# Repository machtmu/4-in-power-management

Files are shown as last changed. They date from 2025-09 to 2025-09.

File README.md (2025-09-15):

# 4 Inch Power Management Subsystem
I'm not gonna lie, this was a beast  

As part of the SPRINT ecosystem with MACH, this board was deisgned in the span of 5 days (From architecture to schematic to layout to production). These were not a good 5 days   

## Functionality
4 Cell BMS with high side protection FETs, integrated NVDC charging for up to 5A @ battery voltage, 3 power rails, 5V, 3.3V @ ~3A, 24V @1.8A (Shoutout Tristan)   
BMS supports up to ~5.7A due to the FET's, but if re speced, could probably go higher   
XT30's as output for 24V, input for charger and input for battery   
JST XH as input for cell balacing   
 Low side current sensing for OCP detection (or wtv else you need current for)  
 ## TODO:  
 I should change that load resistor but lowkey too tired rn :wilted_rose:   
 Order it lmao  
# Authors:  
 Architecture: javezki  
 BMS, 5V 3.3V: javezki  
 Charger, 24V Boost: kayessi 
 Layout: javezki
---

<div align="center">
  <div>
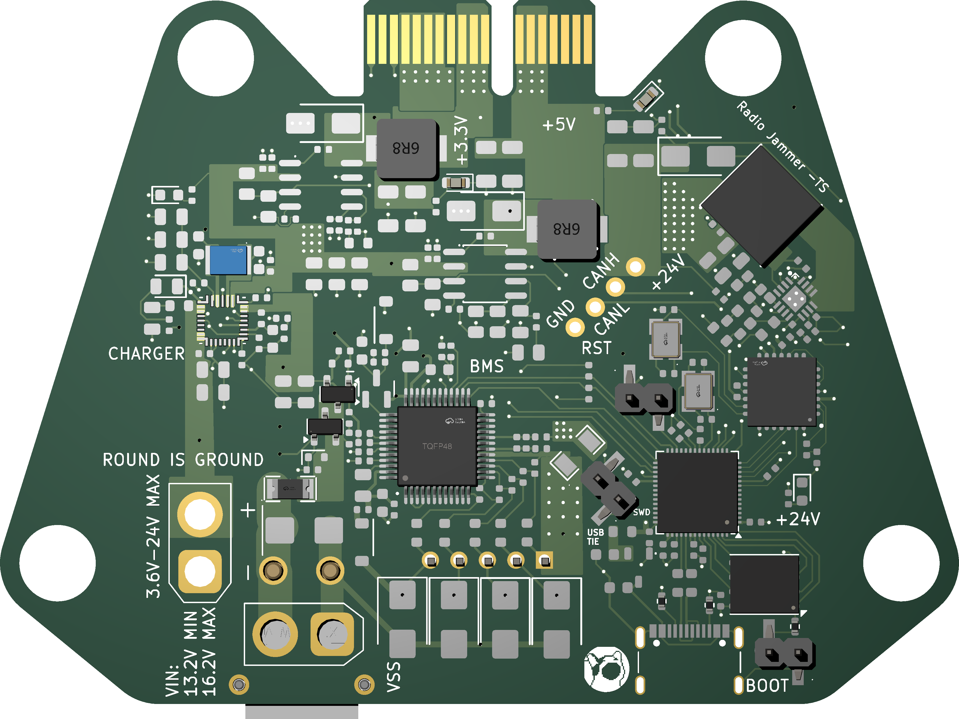
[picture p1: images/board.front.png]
    
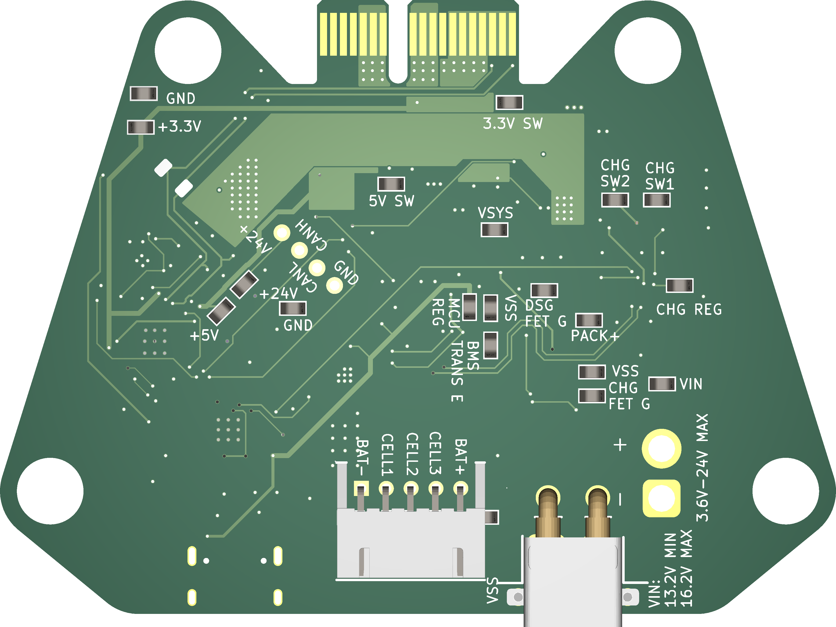
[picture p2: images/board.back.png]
    
    <p><em>3D Render</em></p>
  </div>
  <br>

  <div>
    Schematic<br>
    <p><em>Schematic</em></p>
  </div>
  <br>
  
  <div>
    Front
    Back<br>
    <em>Footprint</em>
  </div>
</div>

Use Export KiCad Images Workflow

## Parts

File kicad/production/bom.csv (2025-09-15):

Designator | Footprint | Quantity | Value | LCSC Part #
C1, C2, C33, C34, C36, C75 | C_0603 | 6 | 1uF | C15849
C10, C17 | C_0402 | 2 | 1uF | C52923
C11, C12, C23, C24, C25, C26, C78 | C_0402 | 7 | 220nF | C16772
C13, C14, C15, C16, C18, C29, C37, C38, C46, C47, C5, C51, C6, C61, C67, C7, C74, C76, C77, C8, C81, C9 | C_0402 | 22 | 100nF | C307331
C19 | C_0402 | 1 | 4.7nF | C1538
C20 | C_0805 | 1 | 33pF | C107115
C21, C41 | C_0402 | 2 | 1nF | C1523
C22 | C_0402 | 1 | 47pF | C1567
C27, C70 | C_0805 | 2 | 1uF | C28323
C28, C32 | C_0402 | 2 | 100pF | C1546
C3, C4 | C_0402 | 2 | 15pF | C1548
C30 | C_0402 | 1 | 2.2uF | C12530
C31 | C_0805 | 1 | 470nF | C13967
C35 | C_0805 | 1 | 22uF | C45783
C39, C43, C44 | C_0603 | 3 | 47nF | C1622
C40, C42, C49, C50, C52, C53, C54, C55, C56, C57 | C_0805 | 10 | 10uF | C440198
C45, C58, C59, C64, C65 | C_0402 | 5 | 4.7uF | C23733
C48 | C_0805 | 1 | 2.2uF | C377773
C60, C66, C73 | C_0402 | 3 | 10nF | C15195
C62, C63, C68, C69 | C_1206 | 4 | 47uF | C96123
C71 | C_0603 | 1 | 330pF | C1664
C72 | C_0603 | 1 | 8.2nF | C1322360
C79, C80 | C_1206 | 2 | 4.7uF | C29823
D1, D2 | 0603 | 2 | LED | C2286
D10, D11 | D_SOD-123 | 2 | BAT46W | C7420332
D12, D9 | D_SOD-523 | 2 | BZX584C12 | C22395579
D13 | D_0805 | 1 | Green | C2297
D14, D15 | D_SMA | 2 | SSL54 | C41410770
D16 | D_SMA | 1 | SS54 | C22452
D17, D3 | D_0603 | 2 | Yellow | C89811
D4, D5, D6, D7, D8 | D_SMB | 5 | SMBJ18A | C19077573
F1 | F1206 | 1 | 0501015_WR | C126815
J1 | USB_C_Receptacle_Palconn_UTC16-G | 1 | USB_C_Receptacle_USB2.0_16P | C2765186
L1 | IND-SMD_L3.2-W2.5-1 | 1 | 1uH | C5159968
L2 | IND-SMD_L7.5-W7.5_XAL7030 | 1 | 2.7uH | C5366402
Q1 | Q_SOT-23 | 1 | FMMT493 | C28646275
Q2, Q3 | SOT-23 | 2 | AO3400A
R1, R12, R13, R2 | 0402 | 4 | 5.1k | C25905
R10, R9 | 0402 | 2 | 27 | C25100
R11, R28, R29, R30, R31, R34, R37, R40, R42, R5, R56, R57 | R_0402 | 12 | 10kΩ | C25744
R14 | R_0805 | 1 | 6.2kΩ | C17767
R15 | R_0805 | 1 | 1.2kΩ | C17379
R16 | R_0805 | 1 | 51kΩ | C17737
R17, R41 | R_0402 | 2 | 7.5kΩ | C25918
R18 | R_0402 | 1 | 2.4kΩ | C25882
R19 | R_0603 | 1 | 30kΩ | C22984
R20, R21, R22, R23, R24 | R_0603 | 5 | 20Ω | C22950
R25, R27, R32, R35, R36, R39 | R_0402 | 6 | 100Ω | C25076
R26 | R0805 | 1 | 5mΩ | C92742
R3, R4, R7 | 0402 | 3 | 1k | C11702
R33, R38 | R_0402 | 2 | 10MΩ | C26082
R43 | R_0402 | 1 | 2.2kΩ | C25879
R44 | R_0603 | 1 | 2Ω | C22977
R45, R47 | R_0805 | 2 | 330kΩ | C17629
R46, R48 | R_0805 | 2 | 100kΩ | C149504
R49, R50 | R_0603 | 2 | 470Ω | C23179
R51 | R_0603 | 1 | 9.1kΩ | C23260
R52 | R_0603 | 1 | 5.1Ω | C25197
R53 | R_0402 | 1 | 47kΩ | C25792
R54 | R_0402 | 1 | 2kΩ | C4109
R55 | R_0402 | 1 | 47Ω | C25118
R6 | R_0603 | 1 | 0Ω | C21189
R8 | R_0402 | 1 | 1kΩ | C11702
TP1, TP10, TP11, TP12, TP13, TP14, TP15, TP16, TP17, TP18, TP19, TP2, TP20, TP21, TP22, TP23, TP24, TP3, TP4, TP5, TP6, TP7, TP8, TP9 | SMD_RH-5015 | 24 | RH-5015 | C5199798
U1 | SOT-23-3_L2.9-W1.6-P1.90-LS2.8-BR | 1 | XC6206P332MR | C5446
U10 | IC_BQ25672RQMR | 1 | BQ25672RQMR | C3682029
U11, U13 | SOIC-8_L5.0-W4.0-P1.27-LS6.0-BL | 2 | TPS54331DR | C9865
U12, U14 | IND-SMD_L5.4-W5.2_SLO0530H6R8MTT | 2 | 6.8uH | C325965
U15 | WQFN-16_L3.0-W3.0-P0.50-TL-EP1.7 | 1 | LM5157RTER | C5219222
U17, U2, U4 | HDR-SMD_2P-P2.54-V-M-S4.8_DZ254S-11-02-50 | 3 | 2P SMD 2.54P Jumper | C17702633
U3 | WSON-8-1EP_6x5mm_P1.27mm_EP3.4x4.3mm | 1 | W25Q128JVP | C190862
U5 | QFN-28_L6.0-W6.0-P0.65-BL-EP3.7 | 1 | MCP25625T-E/ML | C191253
U6 | QFN-56-1EP_7x7mm_P0.4mm_EP3.2x3.2mm | 1 | RP2040 | C2040
U7 | CONN-TH_5P-P2.50_S5B-XH-A-LF-SN | 1 | S5B-XH-A(LF)(SN) | C263757
U8 | CONN-TH_XT30PW-M | 1 | XT30PW-M | C431092
U9 | TQFP-48_L7.0-W7.0-P0.50-LS9.0-TL | 1 | BQ7694202PFBR | C3682863
X1 | CRYSTAL-SMD_4P-L3.2-W2.5-BL | 1 | ABM8-272-T3 | C20625731
Y1 | CRYSTAL-SMD_4P-L3.2-W2.5-BL | 1 | X322516MLB4SI | C12668

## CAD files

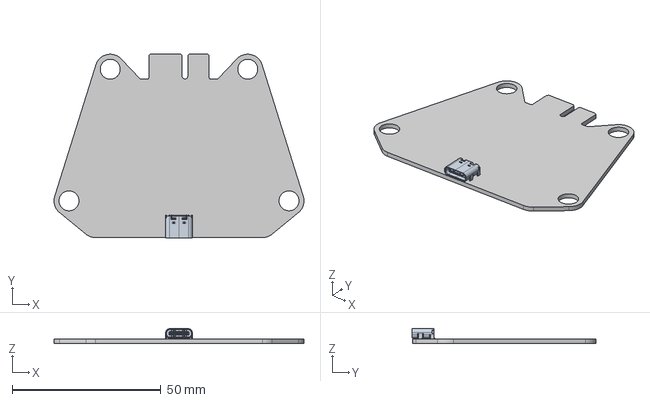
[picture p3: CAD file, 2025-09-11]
images/board.step
84.1 x 61.9 x 4.91 mm
USB_C_Receptacle_GCT_USB4105-xx-A_16P_TopMnt_Horizontal
template_PCB

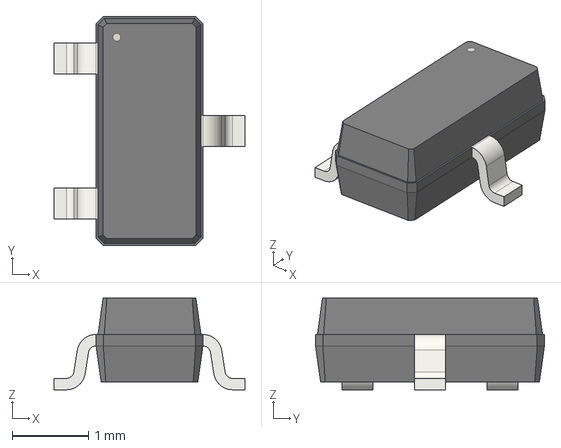
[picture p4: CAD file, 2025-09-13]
kicad/models/SOT-23.step
2.50 x 3.00 x 1.20 mm

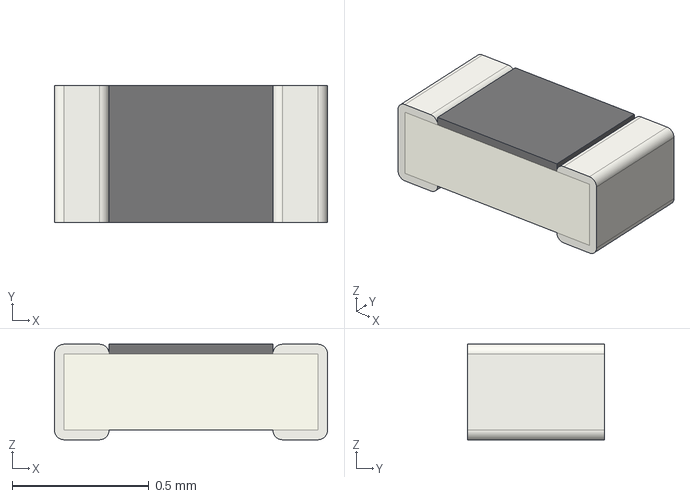
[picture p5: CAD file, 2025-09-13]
kicad/models/R_0402_1005Metric.step
1.00 x 0.5 x 0.35 mm

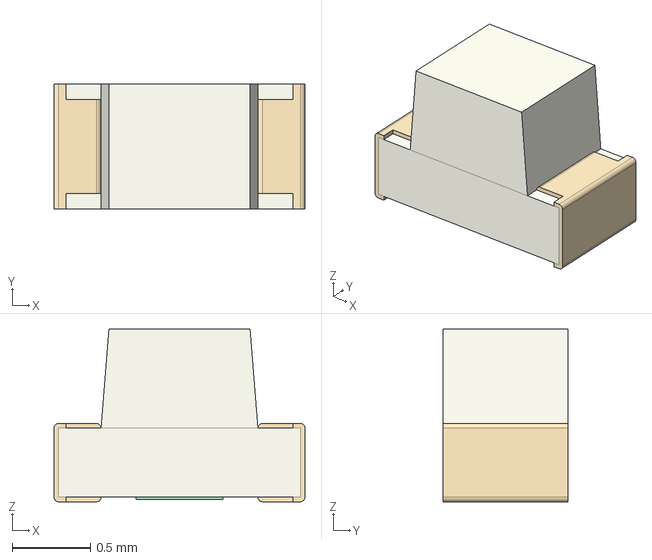
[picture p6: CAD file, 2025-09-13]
kicad/models/LED_0603_1608Metric.step
1.60 x 0.8 x 1.10 mm

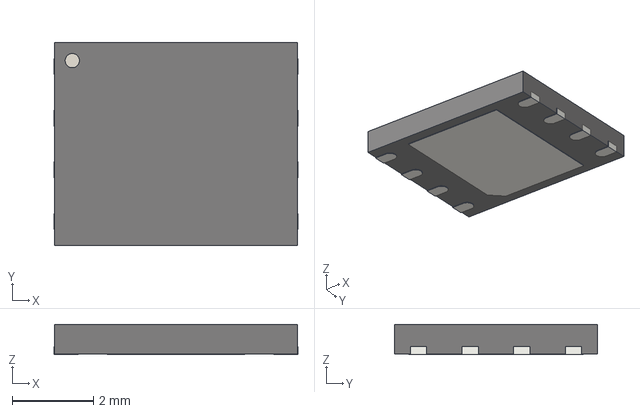
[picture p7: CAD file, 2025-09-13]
kicad/models/WSON-8-1EP_6x5mm_P1.27mm_EP3.4x4.3mm.step
6.00 x 4.98 x 0.75 mm

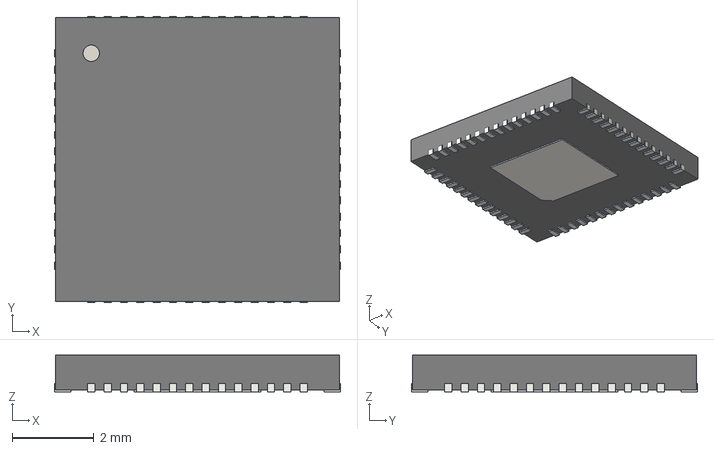
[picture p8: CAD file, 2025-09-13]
kicad/models/QFN-56-1EP_7x7mm_P0.4mm_EP3.2x3.2mm.step
7.00 x 7.00 x 0.9 mm

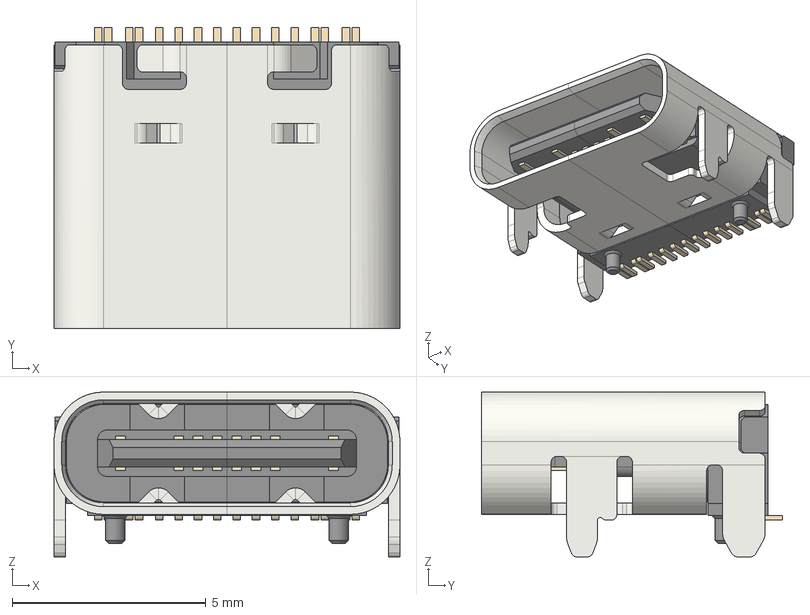
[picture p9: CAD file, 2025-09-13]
kicad/models/USB_C_Receptacle_GCT_USB4105-xx-A_16P_TopMnt_Horizontal.step
8.94 x 7.78 x 4.26 mm

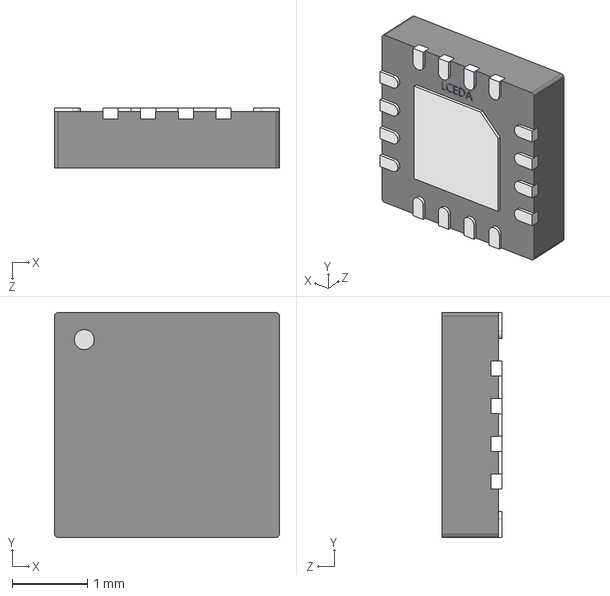
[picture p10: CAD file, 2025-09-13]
kicad/models/WQFN-16_L3.0-W3.0-P0.50-TL-EP1.7.step
3.00 x 3.00 x 0.8 mm

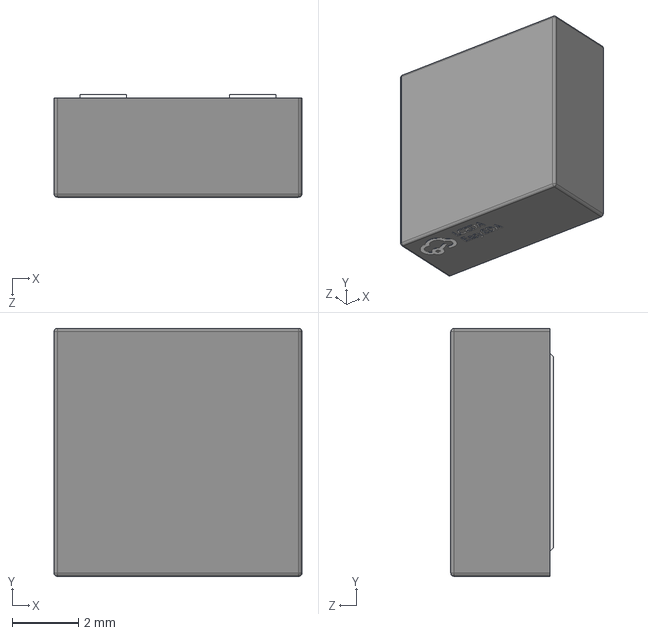
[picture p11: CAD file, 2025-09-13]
kicad/models/IND-SMD_L7.5-W7.5_XAL7030.step
7.50 x 7.51 x 3.10 mm

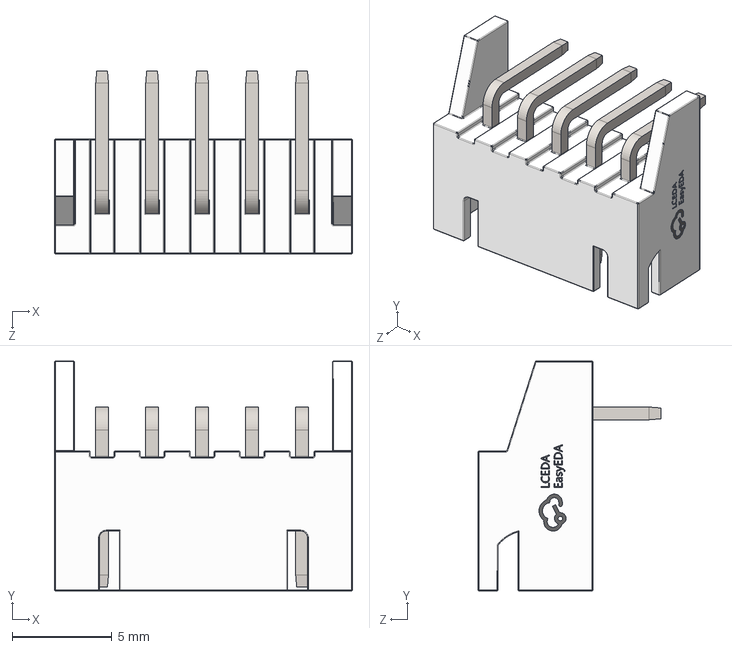
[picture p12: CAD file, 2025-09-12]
kicad/models/CONN-TH_5P-P2.50_S5B-XH-A-LF-SN.step
14.9 x 11.5 x 9.15 mm

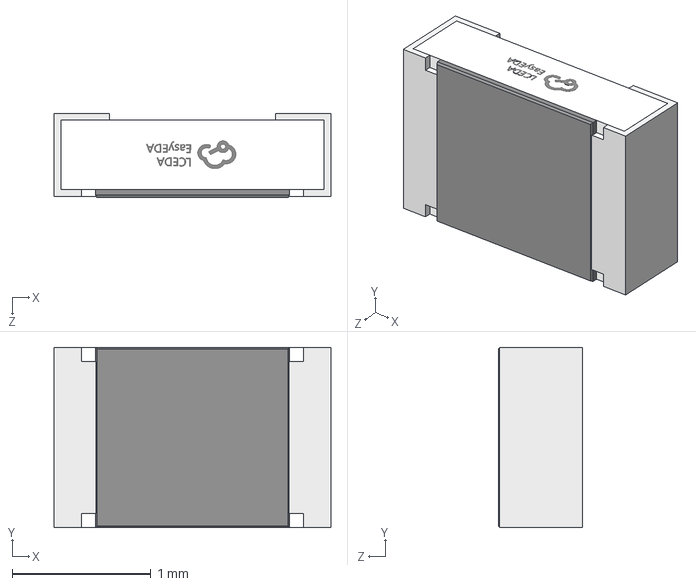
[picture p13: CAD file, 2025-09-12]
kicad/models/R0805.step
2.00 x 1.30 x 0.61 mm

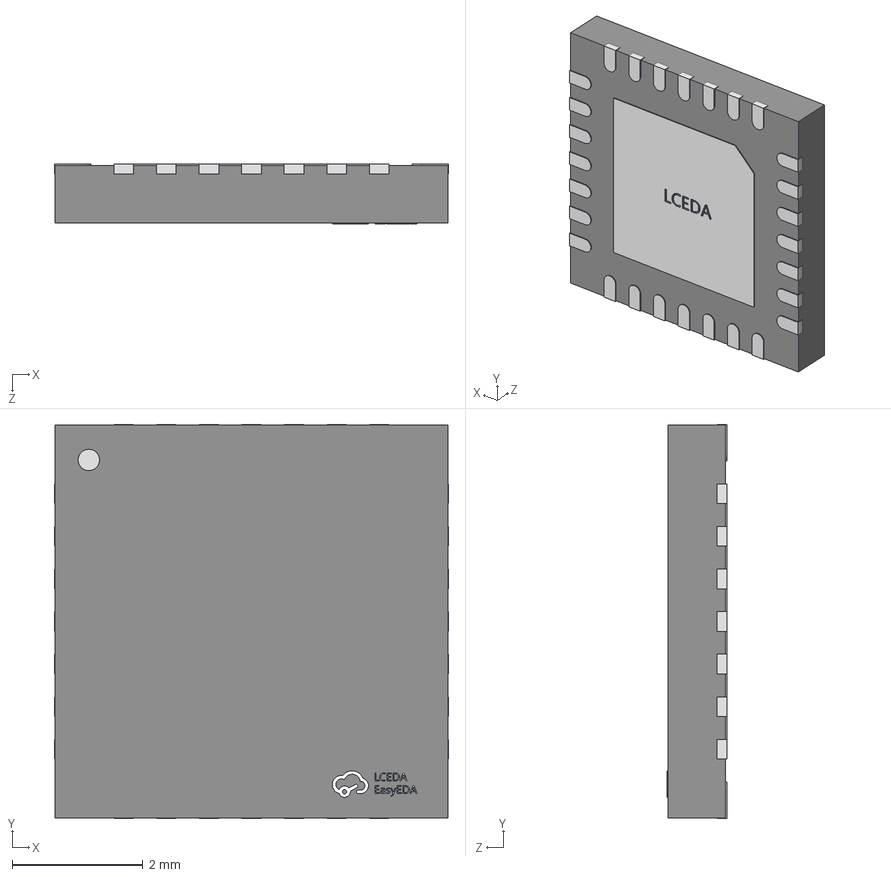
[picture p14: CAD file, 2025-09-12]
kicad/models/QFN-28_L6.0-W6.0-P0.65-BL-EP3.7.step
6.02 x 6.02 x 0.91 mm

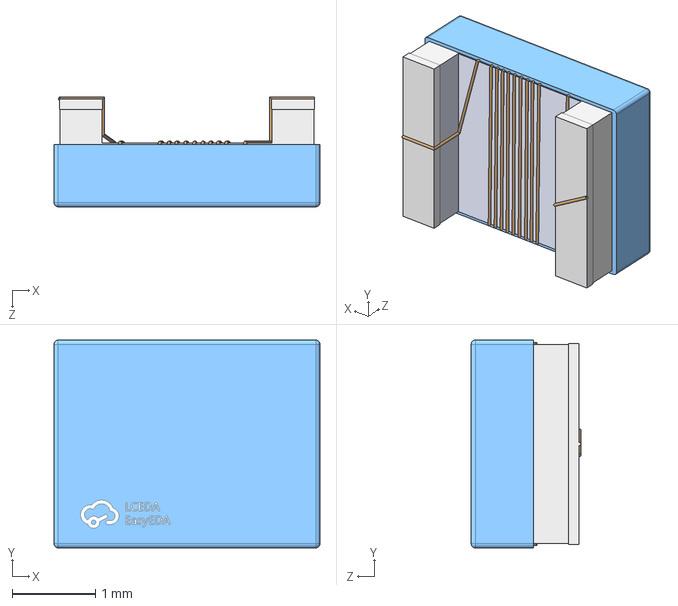
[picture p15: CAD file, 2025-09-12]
kicad/models/IND-SMD_L3.2-W2.5-1.step
3.20 x 2.50 x 1.32 mm

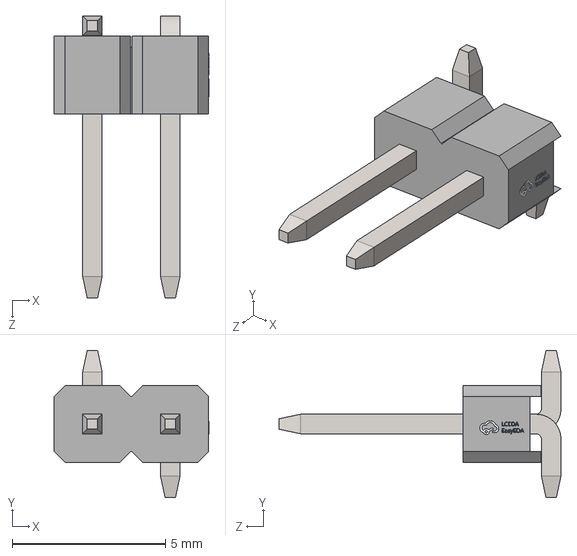
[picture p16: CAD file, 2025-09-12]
kicad/models/HDR-SMD_2P-P2.54-V-M-S4.8_DZ254S-11-02-50.step
5.05 x 4.80 x 9.20 mm

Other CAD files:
kicad/models/CONN-SMD_S4B-XH-SM4-TB-LF-SN.step
kicad/models/F1206.step
kicad/models/SOT-223-3_L6.5-W3.4-P2.30-LS7.0-BR.step
kicad/models/CONN-TH_XT30PW-M.step
kicad/models/CRYSTAL-SMD_4P-L3.2-W2.5-BL.step
kicad/models/IND-SMD_L5.4-W5.2_SLO0530H6R8MTT.step
kicad/models/SMD_RH-5015.step
kicad/models/SOT-23-6_L2.9-W1.6-P0.95-LS2.8-BL.step

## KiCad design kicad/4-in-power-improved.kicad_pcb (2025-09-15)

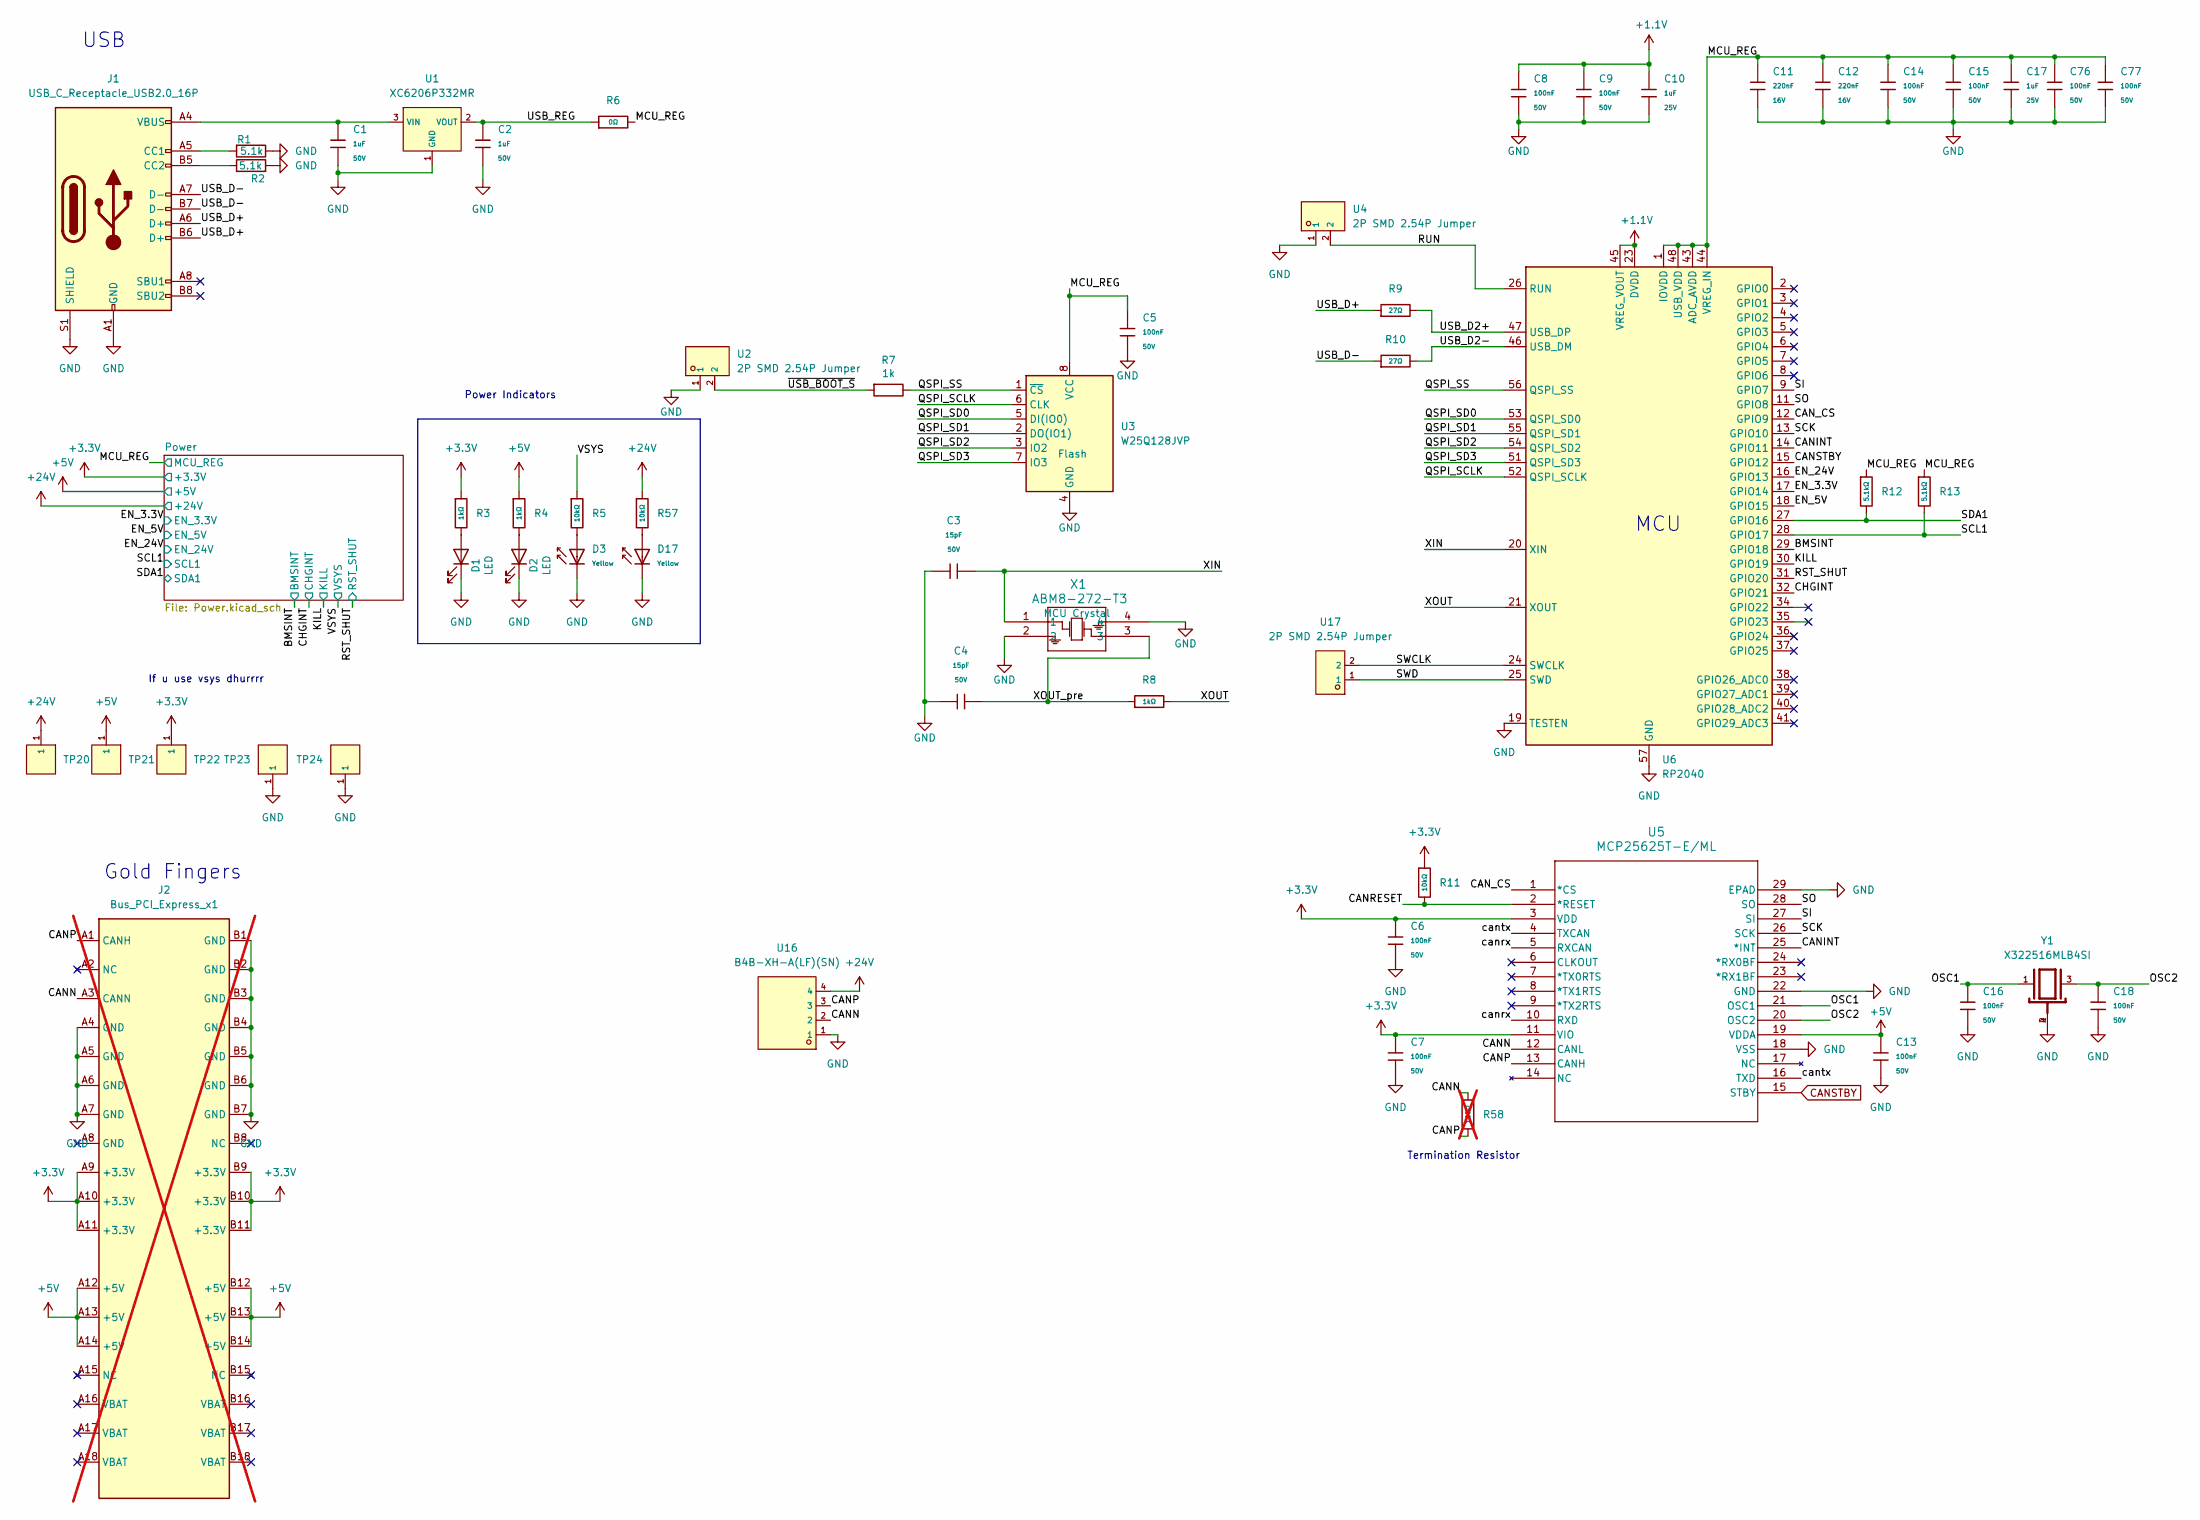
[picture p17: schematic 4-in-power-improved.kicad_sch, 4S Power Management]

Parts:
C1, C2: 1uF; C_0603; Voltage Rated 50V; Tolerance ±10%; Part CL10A105KB8NNNC; LCSC C15849
C3, C4: 15pF; C_0402; Voltage Rated 50V; Tolerance ±5%; Part 0402CG150J500NT; LCSC C1548
C5, C6, C7, C8, C9, C13, C14, C15, C16, C18, C76, C77: 100nF; C_0402; Voltage Rated 50V; Tolerance ±10%; Part CL05B104KB54PNC; LCSC C307331
C10, C17: 1uF; C_0402; Voltage Rated 25V; Tolerance ±10%; Part CL05A105KA5NQNC; LCSC C52923
C11, C12: 220nF; C_0402; Voltage Rated 16V; Tolerance ±10%; Part CL05B224KO5NNNC; LCSC C16772
D1, D2: LED; LED_0603_1608Metric; LCSC PN C2286
D3, D17: Yellow; D_0603; Forward Voltage (VF) 1.6V~2.6V; Part NCD0603Y2; LCSC C89811
J1: USB_C_Receptacle_USB2.0_16P; USB_C_Receptacle_Palconn_UTC16-G; LCSC PN C2765186
J2: Bus_PCI_Express_x1; PCIeX1; not fitted
R1, R2: 5.1k; R_0402_1005Metric; LCSC PN C25905
R3, R4, R8: 1kΩ; R_0402; Overload Voltage (Max) 50V; Tolerance ±1%; Part 0402WGF1001TCE; LCSC C11702
R5, R11, R57: 10kΩ; R_0402; Overload Voltage (Max) 50V; Tolerance ±1%; Part 0402WGF1002TCE; LCSC C25744
R6: 0Ω; R_0603; Overload Voltage (Max) 75V; Tolerance ±1%; Part 0603WAF0000T5E; LCSC C21189
R7: 1k; R_0402_1005Metric; LCSC Part # C11702
R9, R10: 27Ω; R_0603; Overload Voltage (Max) 75V; Tolerance ±1%; Part 0603WAF270JT5E; LCSC C25190
R12, R13: 5.1kΩ; R_0402; Overload Voltage (Max) 50V; Tolerance ±1%; Part 0402WGF5101TCE; LCSC C25905
R58: 120Ω; R_1206; Overload Voltage (Max) 200V; Tolerance ±1%; Part 1206W4F1200T5E; LCSC C17909; not fitted
TP20, TP21, TP22, TP23, TP24: RH-5015; SMD_RH-5015; LCSC C5199798
U1: XC6206P332MR; SOT-23-3_L2.9-W1.6-P1.90-LS2.8-BR; Output Voltage 3.3V; Dropout Voltage 680mV@(100mA); Part XC6206P332MR-G; LCSC C5446
U2, U4, U17: 2P SMD 2.54P Jumper; HDR-SMD_2P-P2.54-V-M-S4.8_DZ254S-11-02-50; LCSC C17702633
U3: W25Q128JVP; WSON-8-1EP_6x5mm_P1.27mm_EP3.4x4.3mm; LCSC C190862
U5: MCP25625T-E/ML; QFN-28_L6.0-W6.0-P0.65-BL-EP3.7; LCSC Part # C191253
U6: RP2040; QFN-56-1EP_7x7mm_P0.4mm_EP3.2x3.2mm; LCSC C2040
U16: B4B-XH-A(LF)(SN); CONN-TH_B4B-XH-A-LF-SN; LCSC C144395
X1: ABM8-272-T3; CRYSTAL-SMD_4P-L3.2-W2.5-BL; LCSC Part # C20625731
Y1: X322516MLB4SI; CRYSTAL-SMD_4P-L3.2-W2.5-BL; PARTREV N/A; LCSC Part # C12668

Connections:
+1.1V: C8.1, C9.1, C10.1, U6.23 (DVDD), U6.45 (VREG_VOUT), U6.50 (DVDD)
+3.3V: C6.1, C7.1, J2.A9 (+3.3V), J2.A10 (+3.3V), J2.A11 (+3.3V), J2.B9 (+3.3V), J2.B10 (+3.3V), J2.B11 (+3.3V), R3.1, R11.1, TP22.1, U5.3 (VDD), U5.11 (VIO); also elsewhere on the board
+5V: C13.1, J2.A12 (+5V), J2.A13 (+5V), J2.A14 (+5V), J2.B12 (+5V), J2.B13 (+5V), J2.B14 (+5V), R4.1, TP21.1, U5.19 (VDDA); also elsewhere on the board
+24V: R57.1, TP20.1, U16.4; also elsewhere on the board
/BMSINT: U6.29 (GPIO18); also elsewhere on the board
/CANINT: U5.25 (*INT), U6.14 (GPIO11)
/CANN: J2.A3 (CANN), R58.1, U5.12 (CANL), U16.2
/CANP: J2.A1 (CANH), R58.2, U5.13 (CANH), U16.3
/CANRESET: R11.2, U5.2 (*RESET)
/CAN_CS: U5.1 (*CS), U6.12 (GPIO9)
/CHGINT: U6.32 (GPIO21); also elsewhere on the board
/EN_3.3V: U6.17 (GPIO14); also elsewhere on the board
/EN_5V: U6.18 (GPIO15); also elsewhere on the board
/EN_24V: U6.16 (GPIO13); also elsewhere on the board
/KILL: U6.30 (GPIO19); also elsewhere on the board
/MCU_REG: C5.1, C11.1, C12.1, C14.1, C15.1, C17.1, C76.1, C77.1, R6.2, R12.1, R13.1, U3.8 (VCC), U6.1 (IOVDD), U6.10 (IOVDD), U6.22 (IOVDD), U6.33 (IOVDD), U6.42 (IOVDD), U6.43 (ADC_AVDD), U6.44 (VREG_IN), U6.48 (USB_VDD), U6.49 (IOVDD); also elsewhere on the board
/OSC1: C16.1, U5.21 (OSC1), Y1.1
/OSC2: C18.1, U5.20 (OSC2), Y1.3
/QSPI_SCLK: U3.6 (CLK), U6.52 (QSPI_SCLK)
/QSPI_SD0: U3.5 (DI(IO0)), U6.53 (QSPI_SD0)
/QSPI_SD1: U3.2 (DO(IO1)), U6.55 (QSPI_SD1)
/QSPI_SD2: U3.3 (IO2), U6.54 (QSPI_SD2)
/QSPI_SD3: U3.7 (IO3), U6.51 (QSPI_SD3)
/QSPI_SS: R7.1, U3.1 (~CS), U6.56 (QSPI_SS)
/RST_SHUT: U6.31 (GPIO20); also elsewhere on the board
/RUN: U4.2, U6.26 (RUN)
/SCK: U5.26 (SCK), U6.13 (GPIO10)
/SCL1: R13.2, U6.28 (GPIO17); also elsewhere on the board
/SDA1: R12.2, U6.27 (GPIO16); also elsewhere on the board
/SI: U5.27 (SI), U6.9 (GPIO7)
/SO: U5.28 (SO), U6.11 (GPIO8)
/SWCLK: U6.24 (SWCLK), U17.2
/SWD: U6.25 (SWD), U17.1
/USB_D2+: R9.2, U6.47 (USB_DP)
/USB_D2-: R10.2, U6.46 (USB_DM)
/USB_D+: J1.A6 (D+), J1.B6 (D+), R9.1
/USB_D-: J1.A7 (D-), J1.B7 (D-), R10.1
/USB_REG: C2.1, R6.1, U1.2 (VOUT)
/VSYS: R5.1; also elsewhere on the board
/XIN: C3.2, U6.20 (XIN), X1.1
/XOUT: R8.2, U6.21 (XOUT)
/XOUT_pre: C4.2, R8.1, X1.3
/canrx: U5.5 (RXCAN), U5.10 (RXD)
/cantx: U5.4 (TXCAN), U5.16 (TXD)
/~USB_BOOT_S: R7.2, U2.2
CANSTBY: U5.15 (STBY), U6.15 (GPIO12)
GND: C1.2, C2.2, C3.1, C4.1, C5.2, C6.2, C7.2, C8.2, C9.2, C10.2, C11.2, C12.2, C13.2, C14.2, C15.2, C16.2, C17.2, C18.2, C76.2, C77.2, D1.1 (K), D2.1 (K), D3.1, D17.1, J1.A1 (GND), J1.A12 (GND), J1.B1 (GND), J1.B12 (GND), J1.S1 (SHIELD), J2.A4 (GND), J2.A5 (GND), J2.A6 (GND), J2.A7 (GND), J2.B1 (GND), J2.B2 (GND), J2.B3 (GND), J2.B4 (GND), J2.B5 (GND), J2.B6 (GND), J2.B7 (GND), R1.1, R2.2, TP23.1, TP24.1, U1.1 (GND), U2.1, U3.4 (GND), U4.1, U5.18 (VSS), U5.22 (GND), U5.29 (EPAD), U6.19 (TESTEN), U6.57 (GND), U16.1, X1.2, X1.4, Y1.2, Y1.4; also elsewhere on the board
unnamed: D1.2 (A), R3.2
unnamed: D2.2 (A), R4.2
unnamed: D3.2, R5.2
unnamed: D17.2, R57.2
unnamed: J1.A5 (CC1), R1.2
unnamed: J1.B5 (CC2), R2.1
unnamed: C1.1, J1.A4 (VBUS), J1.A9 (VBUS), J1.B4 (VBUS), J1.B9 (VBUS), U1.3 (VIN)

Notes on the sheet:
USB
MCU
Power Indicators
Termination Resistor
If u use vsys dhurrrr
Gold Fingers

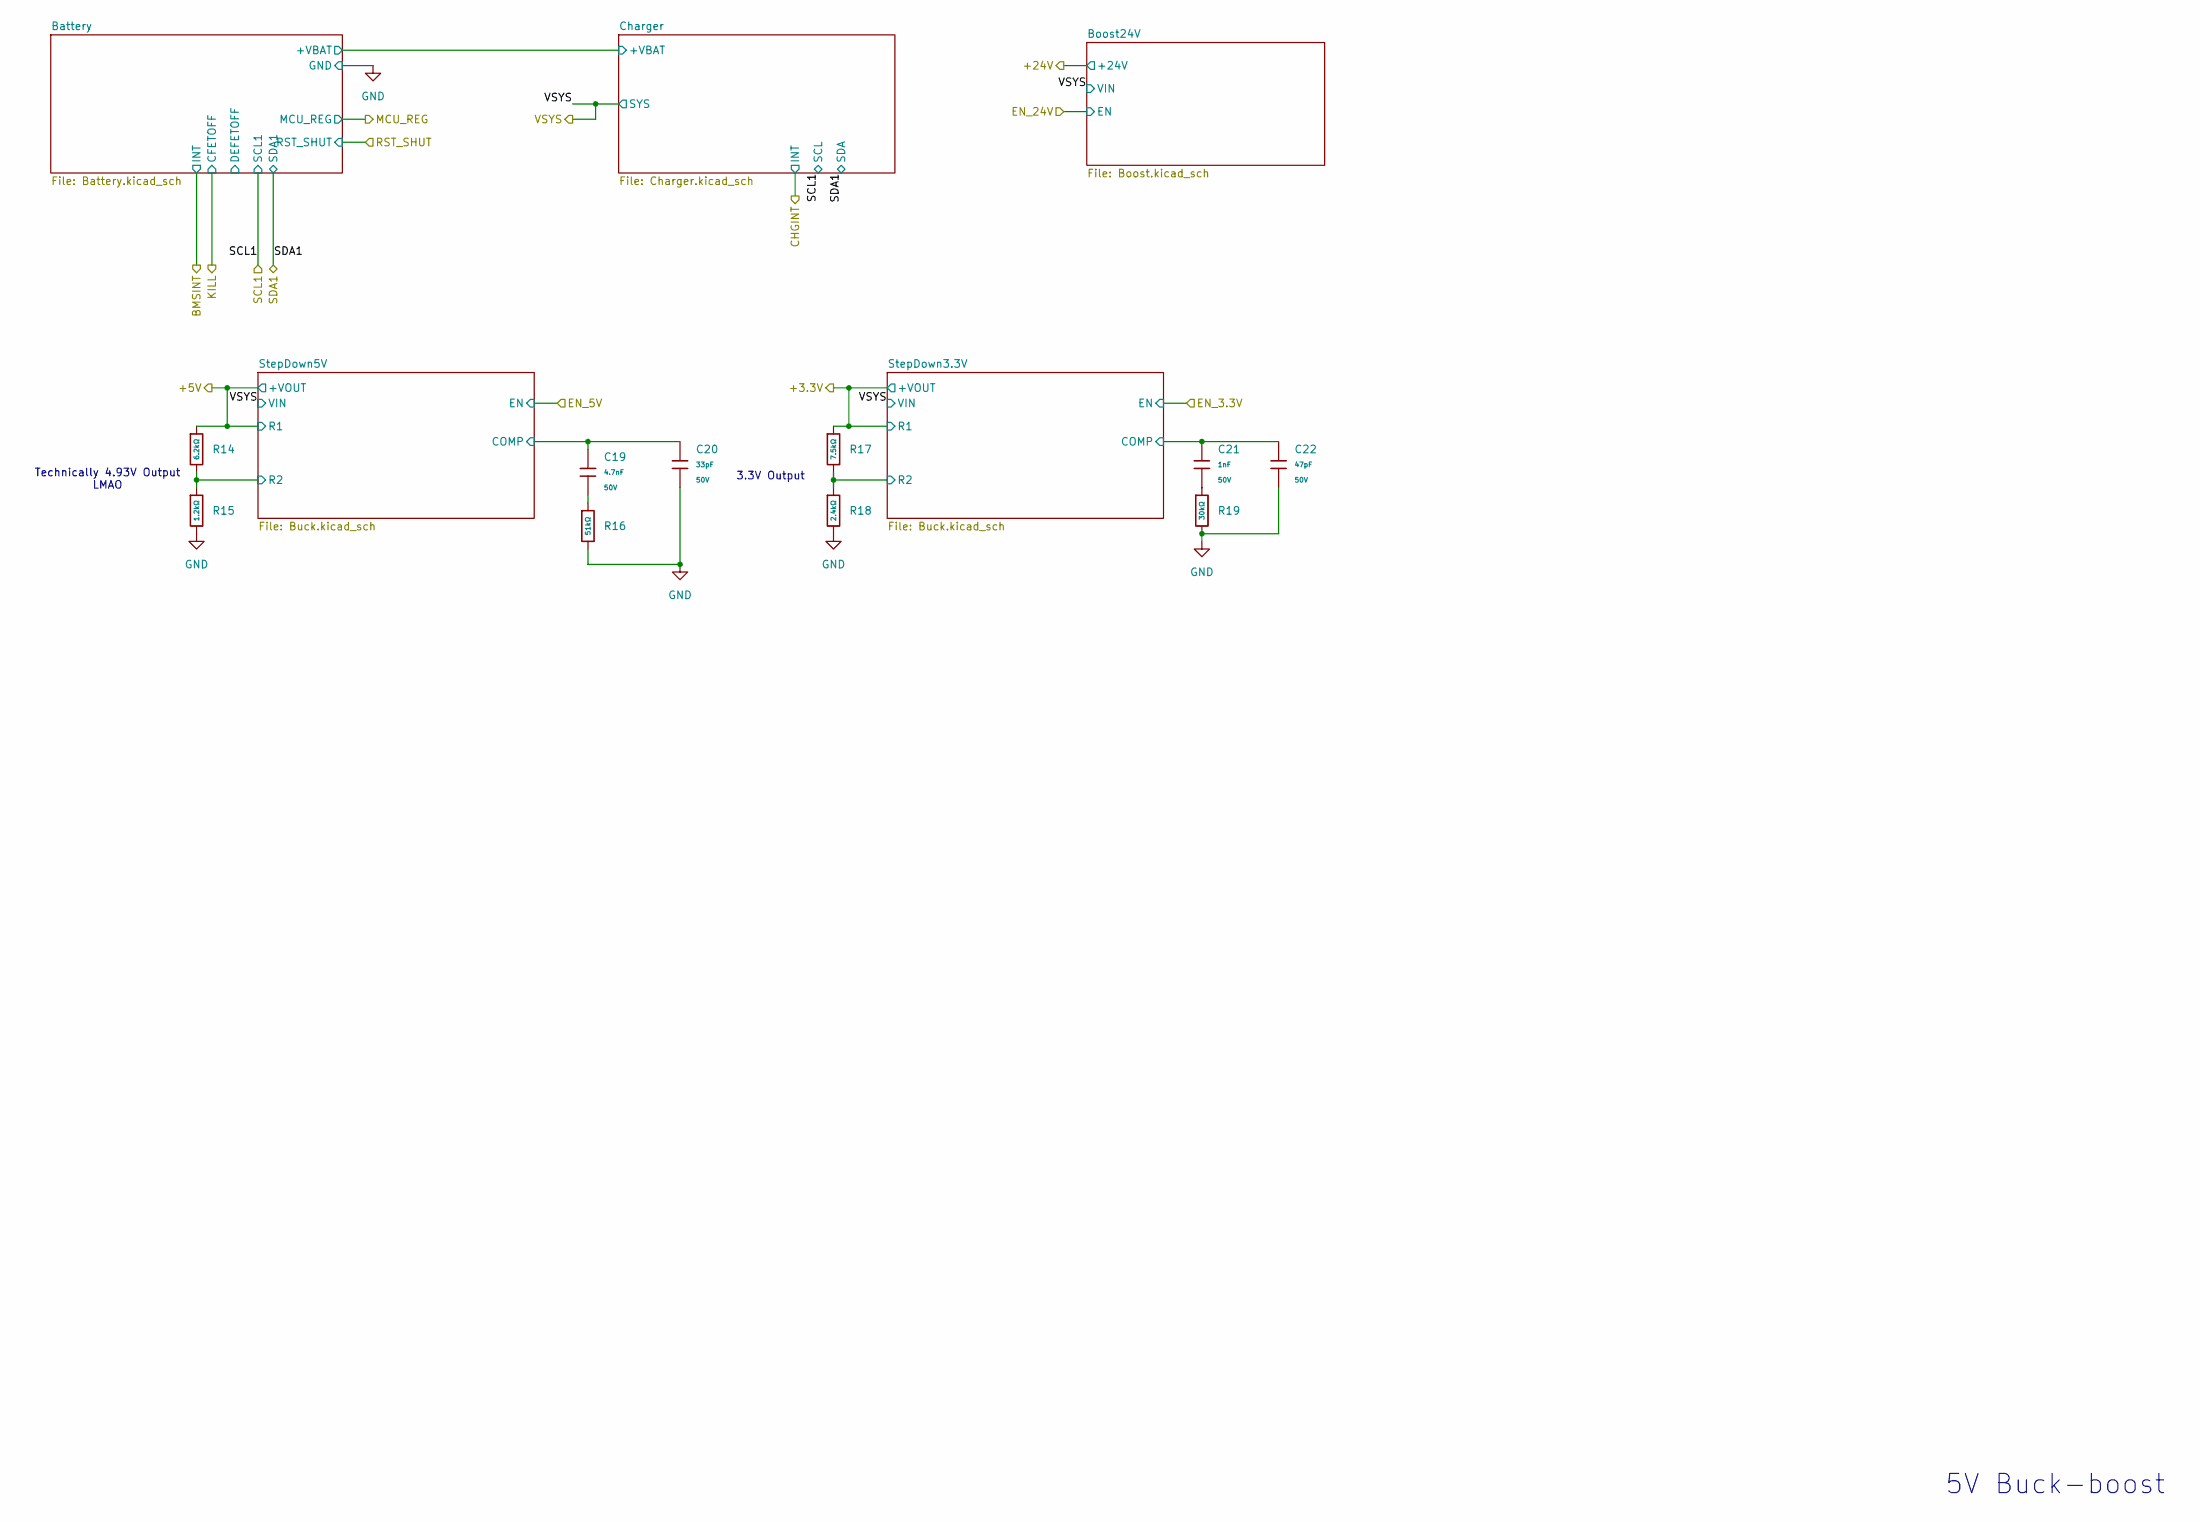
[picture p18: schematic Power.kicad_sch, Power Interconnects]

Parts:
C19: 4.7nF; C_0402; Voltage Rated 50V; Tolerance ±10%; Part 0402B472K500NT; LCSC C1538
C20: 33pF; C_0805; Voltage Rated 50V; Tolerance ±5%; Part CC0805JRNPO9BN330; LCSC C107115
C21: 1nF; C_0402; Voltage Rated 50V; Tolerance ±10%; Part 0402B102K500NT; LCSC C1523
C22: 47pF; C_0402; Voltage Rated 50V; Tolerance ±5%; Part 0402CG470J500NT; LCSC C1567
R14: 6.2kΩ; R_0805; Overload Voltage (Max) 150V; Tolerance ±1%; Part 0805W8F6201T5E; LCSC C17767
R15: 1.2kΩ; R_0805; Overload Voltage (Max) 150V; Tolerance ±1%; Part 0805W8F1201T5E; LCSC C17379
R16: 51kΩ; R_0805; Overload Voltage (Max) 150V; Tolerance ±1%; Part 0805W8F5102T5E; LCSC C17737
R17: 7.5kΩ; R_0402; Overload Voltage (Max) 50V; Tolerance ±1%; Part 0402WGF7501TCE; LCSC C25918
R18: 2.4kΩ; R_0402; Overload Voltage (Max) 50V; Tolerance ±1%; Part 0402WGF2401TCE; LCSC C25882
R19: 30kΩ; R_0603; Overload Voltage (Max) 75V; Tolerance ±1%; Part 0603WAF3002T5E; LCSC C22984

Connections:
+3.3V: R17.1; also elsewhere on the board
+5V: R14.1; also elsewhere on the board
/Power/StepDown3.3V/COMP: C21.1, C22.1; also elsewhere on the board
/Power/StepDown3.3V/R2: R17.2, R18.1; also elsewhere on the board
/Power/StepDown5V/COMP: C19.1, C20.1; also elsewhere on the board
/Power/StepDown5V/R2: R14.2, R15.1; also elsewhere on the board
GND: C20.2, C22.2, R15.2, R16.2, R18.2, R19.2; also elsewhere on the board
unnamed: C19.2, R16.1
unnamed: C21.2, R19.1

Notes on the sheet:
Technically 4.93V Output LMAO
5V Buck-boost
3.3V Output

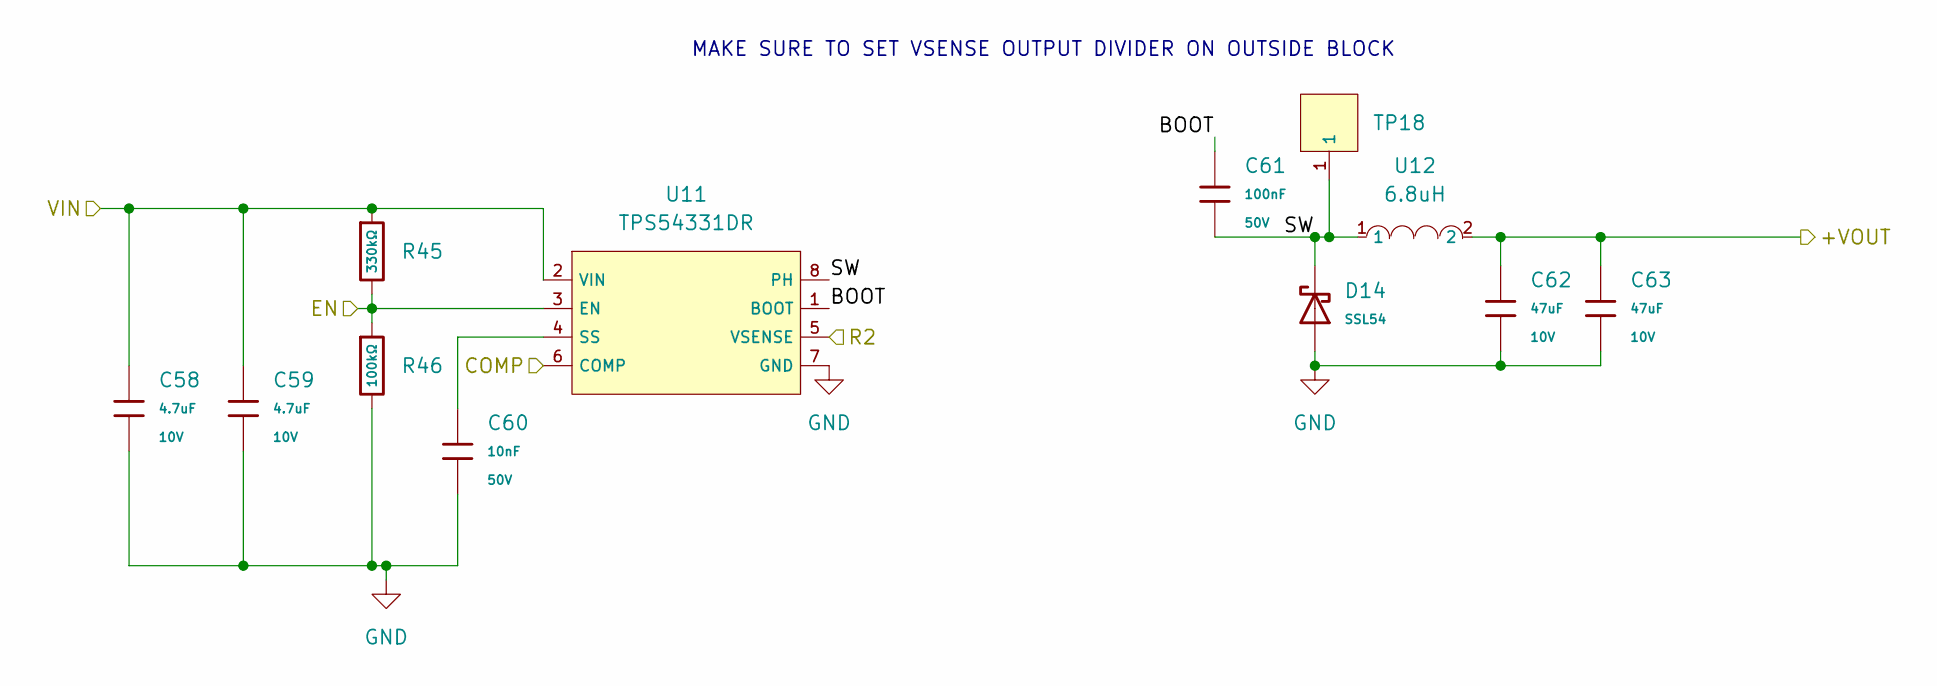
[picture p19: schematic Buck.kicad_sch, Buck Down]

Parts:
C58, C59: 4.7uF; C_0402; Voltage Rated 10V; Tolerance ±20%; Part CL05A475MP5NRNC; LCSC C23733
C60: 10nF; C_0402; Voltage Rated 50V; Tolerance ±10%; Part CL05B103KB5NNNC; LCSC C15195
C61: 100nF; C_0402; Voltage Rated 50V; Tolerance ±10%; Part CL05B104KB54PNC; LCSC C307331
C62, C63: 47uF; C_1206; Voltage Rated 10V; Tolerance ±20%; Part CL31A476MPHNNNE; LCSC C96123
D14: SSL54; D_SMA; Forward Voltage (Vf@If) 480mV@5A; Reverse Voltage (Vr) 40V; Part SSL54; LCSC C41410770
R45: 330kΩ; R_0805; Overload Voltage (Max) 150V; Tolerance ±1%; Part 0805W8F3303T5E; LCSC C17629
R46: 100kΩ; R_0805; Overload Voltage (Max) 150V; Tolerance ±1%; Part 0805W8F1003T5E; LCSC C149504
TP18: RH-5015; SMD_RH-5015; LCSC C5199798
U11: TPS54331DR; SOIC-8_L5.0-W4.0-P1.27-LS6.0-BL; Output Voltage 0.8V~25V; Input Voltage 3.5V~28V; Part TPS54331DR; LCSC C9865
U12: 6.8uH; IND-SMD_L5.4-W5.2_SLO0530H6R8MTT; MFR PART# SLO0530H6R8MTT; LCSC C325965

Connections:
+5V: C62.1, C63.1, U12.2; also elsewhere on the board
/EN_5V: R45.2, R46.1, U11.3 (EN); also elsewhere on the board
/Power/StepDown5V/BOOT: C61.1, U11.1 (BOOT)
/Power/StepDown5V/COMP: U11.6 (COMP); also elsewhere on the board
/Power/StepDown5V/R2: U11.5 (VSENSE); also elsewhere on the board
/Power/StepDown5V/SW: C61.2, D14.1, TP18.1, U11.8 (PH), U12.1
/VSYS: C58.1, C59.1, R45.1, U11.2 (VIN); also elsewhere on the board
GND: C58.2, C59.2, C60.2, C62.2, C63.2, D14.2, R46.2, U11.7 (GND); also elsewhere on the board
unnamed: C60.1, U11.4 (SS)

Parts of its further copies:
C64, C65: 4.7uF; C_0402; Voltage Rated 10V; Tolerance ±20%; Part CL05A475MP5NRNC; LCSC C23733
C66: 10nF; C_0402; Voltage Rated 50V; Tolerance ±10%; Part CL05B103KB5NNNC; LCSC C15195
C67: 100nF; C_0402; Voltage Rated 50V; Tolerance ±10%; Part CL05B104KB54PNC; LCSC C307331
C68, C69: 47uF; C_1206; Voltage Rated 10V; Tolerance ±20%; Part CL31A476MPHNNNE; LCSC C96123
D15: SSL54; D_SMA; Forward Voltage (Vf@If) 480mV@5A; Reverse Voltage (Vr) 40V; Part SSL54; LCSC C41410770
R47: 330kΩ; R_0805; Overload Voltage (Max) 150V; Tolerance ±1%; Part 0805W8F3303T5E; LCSC C17629
R48: 100kΩ; R_0805; Overload Voltage (Max) 150V; Tolerance ±1%; Part 0805W8F1003T5E; LCSC C149504
TP19: RH-5015; SMD_RH-5015; LCSC C5199798
U13: TPS54331DR; SOIC-8_L5.0-W4.0-P1.27-LS6.0-BL; Output Voltage 0.8V~25V; Input Voltage 3.5V~28V; Part TPS54331DR; LCSC C9865
U14: 6.8uH; IND-SMD_L5.4-W5.2_SLO0530H6R8MTT; MFR PART# SLO0530H6R8MTT; LCSC C325965

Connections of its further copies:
+3.3V: C68.1, C69.1, U14.2; also elsewhere on the board
/EN_3.3V: R47.2, R48.1, U13.3 (EN); also elsewhere on the board
/Power/StepDown3.3V/BOOT: C67.1, U13.1 (BOOT)
/Power/StepDown3.3V/COMP: U13.6 (COMP); also elsewhere on the board
/Power/StepDown3.3V/R2: U13.5 (VSENSE); also elsewhere on the board
/Power/StepDown3.3V/SW: C67.2, D15.1, TP19.1, U13.8 (PH), U14.1
/VSYS: C64.1, C65.1, R47.1, U13.2 (VIN); also elsewhere on the board
GND: C64.2, C65.2, C66.2, C68.2, C69.2, D15.2, R48.2, U13.7 (GND); also elsewhere on the board
unnamed: C66.1, U13.4 (SS)

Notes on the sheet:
MAKE SURE TO SET VSENSE OUTPUT DIVIDER ON OUTSIDE BLOCK

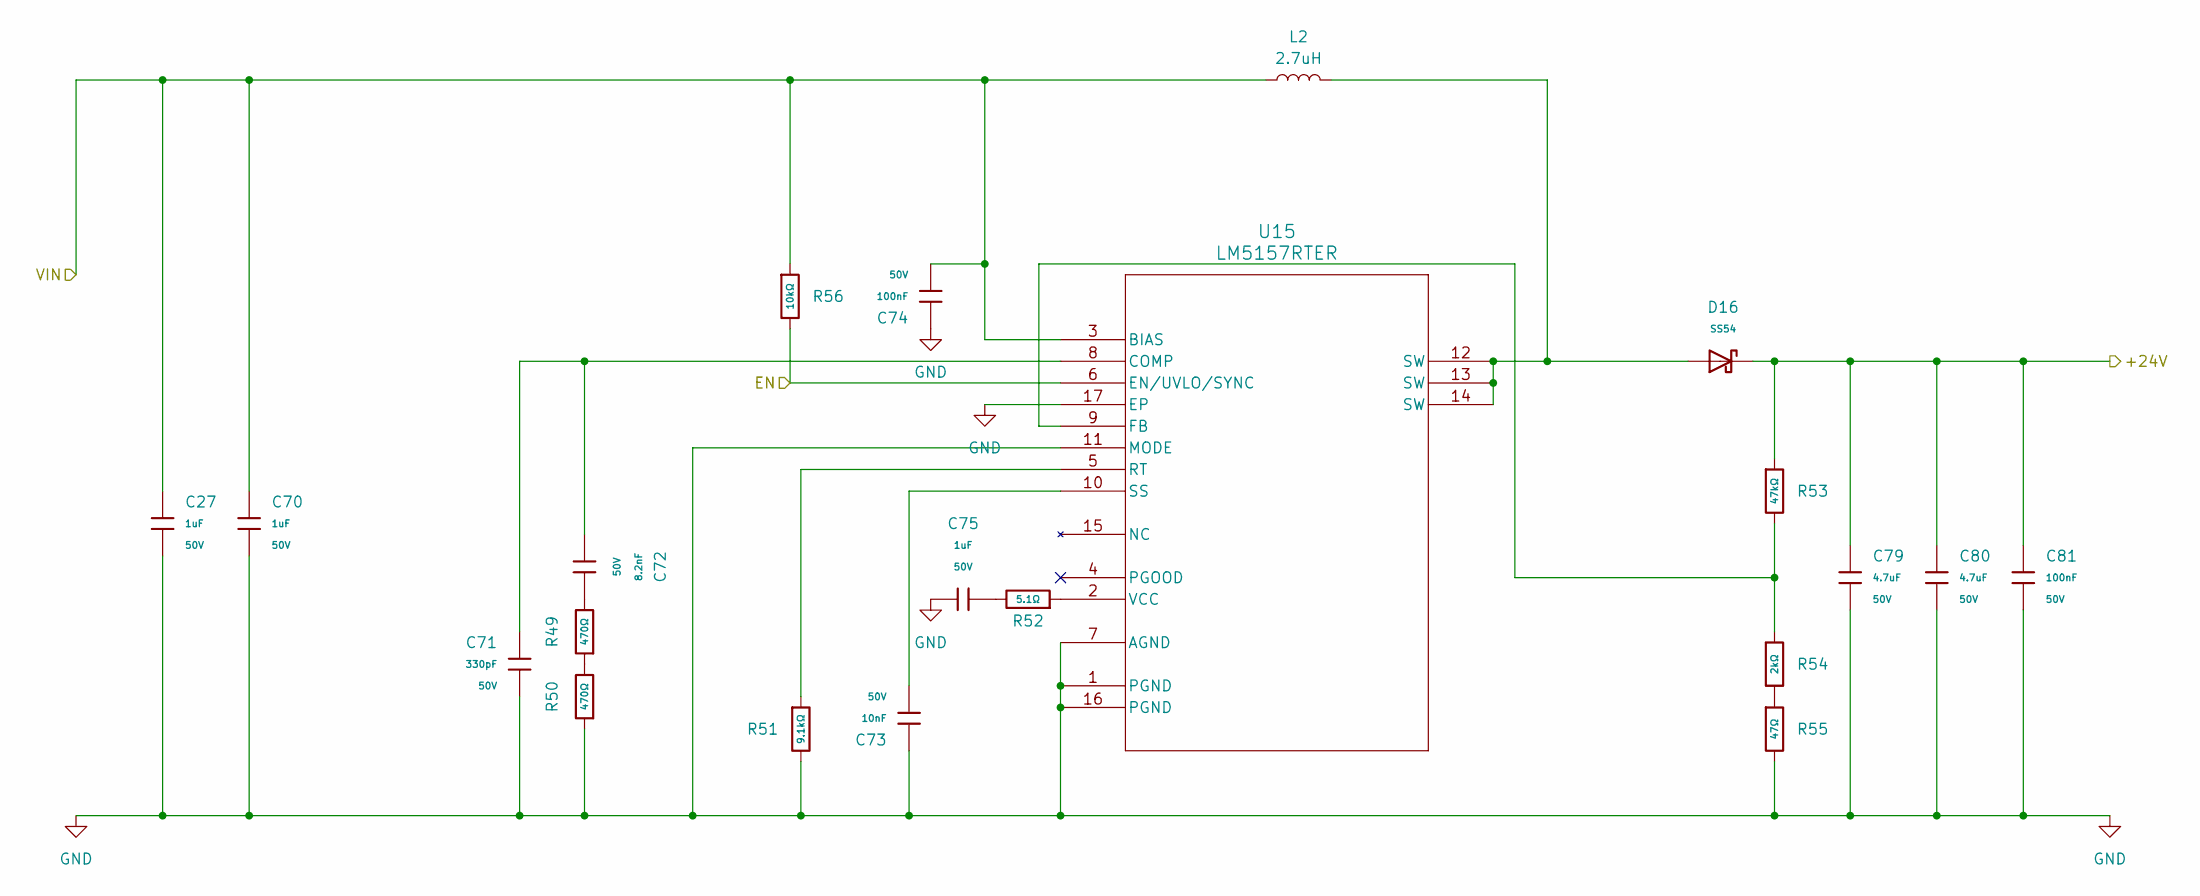
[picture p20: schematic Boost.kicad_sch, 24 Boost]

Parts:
C27, C70: 1uF; C_0805; Voltage Rated 50V; Tolerance ±10%; Part CL21B105KBFNNNE; LCSC C28323
C71: 330pF; C_0603; Voltage Rated 50V; Tolerance ±5%; Part CL10C331JB8NNNC; LCSC C1664
C72: 8.2nF; C_0603; Voltage Rated 50V; Tolerance ±10%; Part 0603B822K500NT; LCSC C1322360
C73: 10nF; C_0402; Voltage Rated 50V; Tolerance ±10%; Part CL05B103KB5NNNC; LCSC C15195
C74, C81: 100nF; C_0402; Voltage Rated 50V; Tolerance ±10%; Part CL05B104KB54PNC; LCSC C307331
C75: 1uF; C_0603; Voltage Rated 50V; Tolerance ±10%; Part CL10A105KB8NNNC; LCSC C15849
C79, C80: 4.7uF; C_1206; Voltage Rated 50V; Tolerance ±10%; Part 1206B475K500NT; LCSC C29823
D16: SS54; D_SMA; Forward Voltage (Vf@If) 550mV@5A; Reverse Voltage (Vr) 40V; Part SS54; LCSC C22452
L2: 2.7uH; IND-SMD_L7.5-W7.5_XAL7030; LCSC C5366402
R49, R50: 470Ω; R_0603; Overload Voltage (Max) 75V; Tolerance ±1%; Part 0603WAF4700T5E; LCSC C23179
R51: 9.1kΩ; R_0603; Overload Voltage (Max) 75V; Tolerance ±1%; Part 0603WAF9101T5E; LCSC C23260
R52: 5.1Ω; R_0603; Overload Voltage (Max) 75V; Tolerance ±1%; Part 0603WAF510KT5E; LCSC C25197
R53: 47kΩ; R_0402; Overload Voltage (Max) 50V; Tolerance ±1%; Part 0402WGF4702TCE; LCSC C25792
R54: 2kΩ; R_0402; Overload Voltage (Max) 50V; Tolerance ±1%; Part 0402WGF2001TCE; LCSC C4109
R55: 47Ω; R_0402; Overload Voltage (Max) 50V; Tolerance ±1%; Part 0402WGF470JTCE; LCSC C25118
R56: 10kΩ; R_0402; Overload Voltage (Max) 50V; Tolerance ±1%; Part 0402WGF1002TCE; LCSC C25744
U15: LM5157RTER; WQFN-16_L3.0-W3.0-P0.50-TL-EP1.7; LCSC C5219222

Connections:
+24V: C79.1, C80.1, C81.1, D16.1, R53.1; also elsewhere on the board
/EN_24V: R56.2, U15.6 (EN/UVLO/SYNC); also elsewhere on the board
/VSYS: C27.1, C70.1, C74.1, L2.1, R56.1, U15.3 (BIAS); also elsewhere on the board
GND: C27.2, C70.2, C71.1, C73.1, C74.2, C75.2, C79.2, C80.2, C81.2, R50.1, R51.2, R55.2, U15.1 (PGND), U15.7 (AGND), U15.11 (MODE), U15.16 (PGND), U15.17 (EP); also elsewhere on the board
unnamed: C72.2, R49.2
unnamed: C75.1, R52.2
unnamed: D16.2, L2.2, U15.12 (SW), U15.13 (SW), U15.14 (SW)
unnamed: R49.1, R50.2
unnamed: R54.2, R55.1
unnamed: C71.2, C72.1, U15.8 (COMP)
unnamed: R53.2, R54.1, U15.9 (FB)
unnamed: R51.1, U15.5 (RT)
unnamed: C73.2, U15.10 (SS)
unnamed: R52.1, U15.2 (VCC)

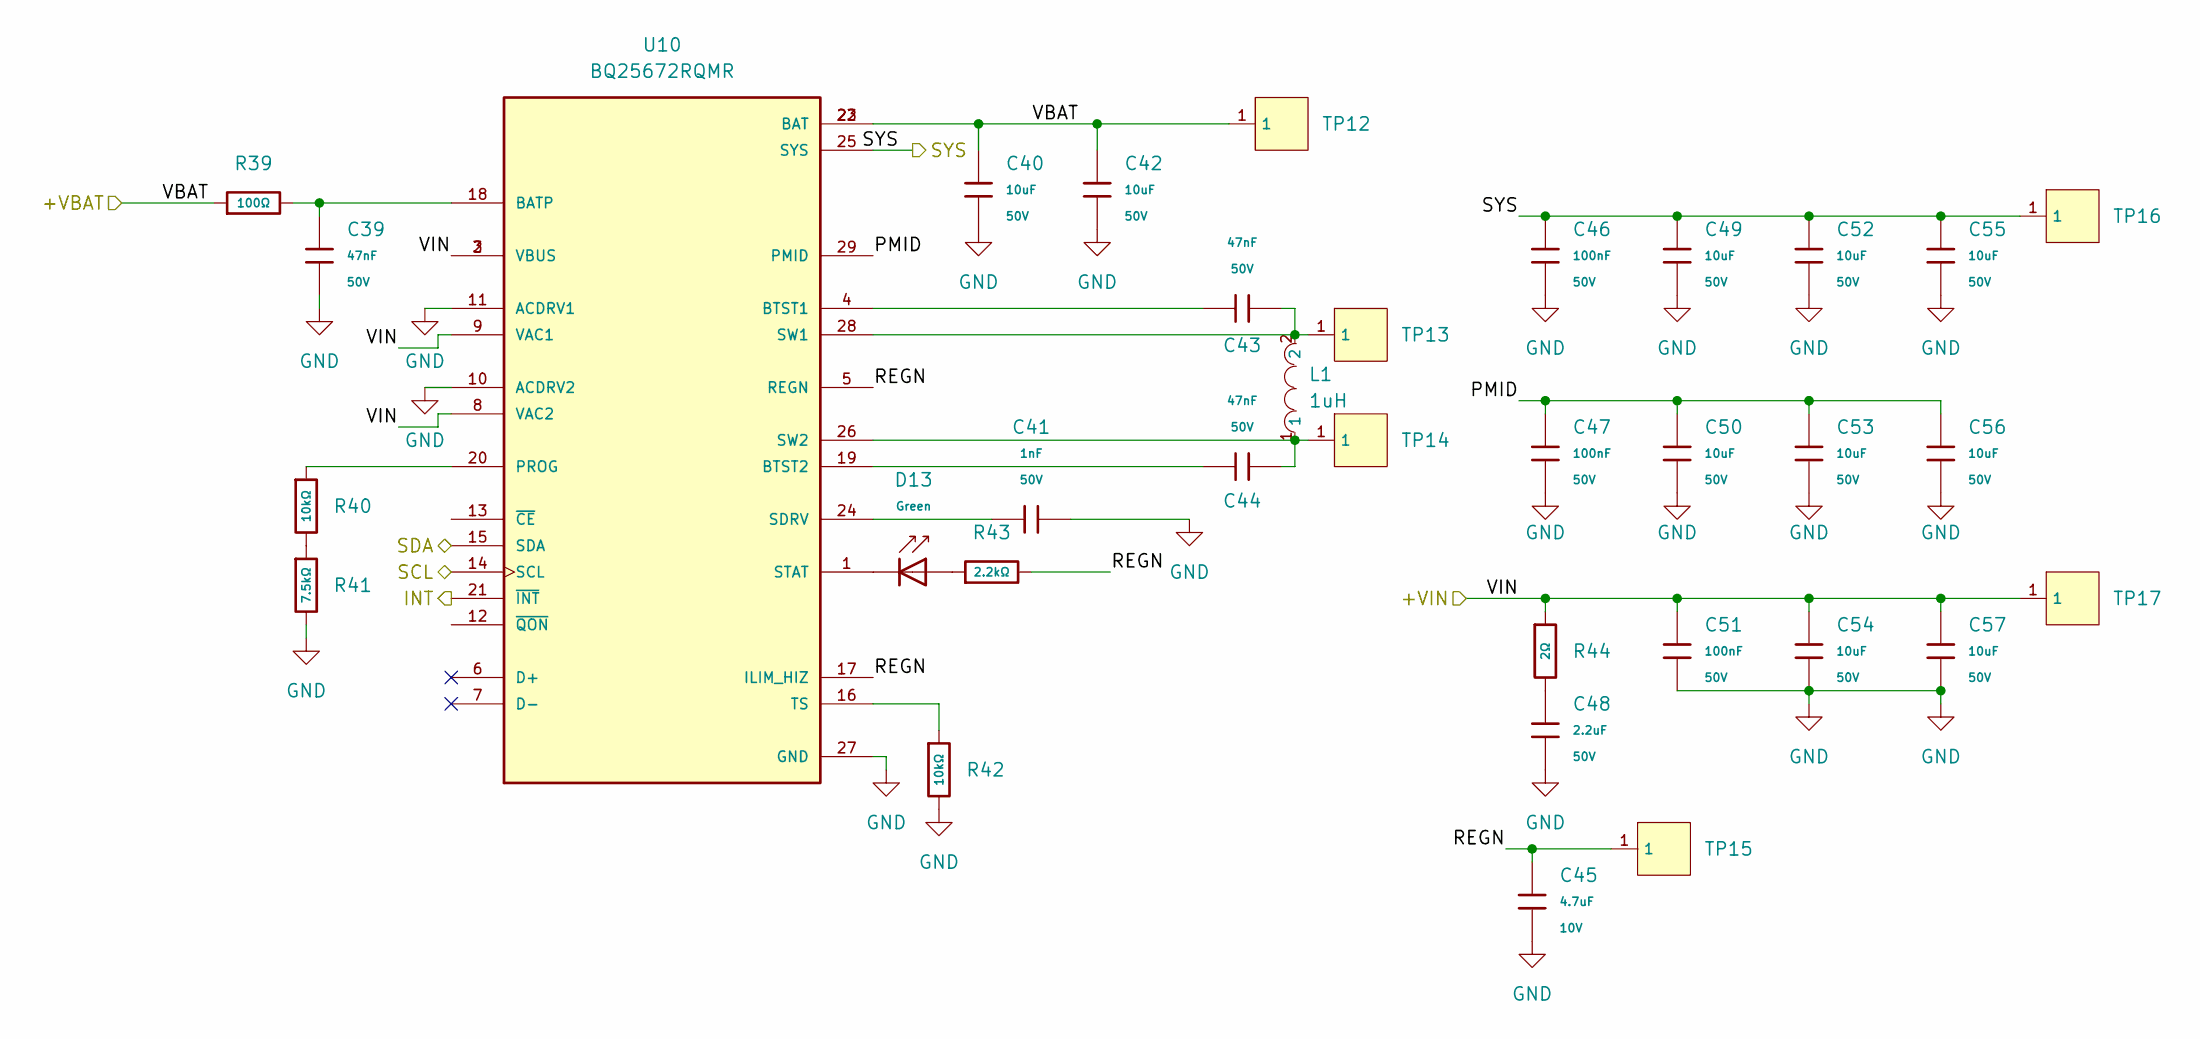
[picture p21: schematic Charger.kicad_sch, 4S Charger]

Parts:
C39, C43, C44: 47nF; C_0603; Voltage Rated 50V; Tolerance ±10%; Part CL10B473KB8NNNC; LCSC C1622
C40, C42, C49, C50, C52, C53, C54, C55, C56, C57: 10uF; C_0805; Voltage Rated 50V; Tolerance ±10%; Part GRM21BR61H106KE43L; LCSC C440198
C41: 1nF; C_0402; Voltage Rated 50V; Tolerance ±10%; Part 0402B102K500NT; LCSC C1523
C45: 4.7uF; C_0402; Voltage Rated 10V; Tolerance ±20%; Part CL05A475MP5NRNC; LCSC C23733
C46, C47, C51: 100nF; C_0402; Voltage Rated 50V; Tolerance ±10%; Part CL05B104KB54PNC; LCSC C307331
C48: 2.2uF; C_0805; Voltage Rated 50V; Tolerance ±10%; Part CL21A225KBQNNNE; LCSC C377773
D13: Green; D_0805; Part KT-0805G; LCSC C2297
L1: 1uH; IND-SMD_L3.2-W2.5-1; LCSC C5159968
R39: 100Ω; R_0402; Overload Voltage (Max) 50V; Tolerance ±1%; Part 0402WGF1000TCE; LCSC C25076
R40, R42: 10kΩ; R_0402; Overload Voltage (Max) 50V; Tolerance ±1%; Part 0402WGF1002TCE; LCSC C25744
R41: 7.5kΩ; R_0402; Overload Voltage (Max) 50V; Tolerance ±1%; Part 0402WGF7501TCE; LCSC C25918
R43: 2.2kΩ; R_0402; Overload Voltage (Max) 50V; Tolerance ±1%; Part 0402WGF2201TCE; LCSC C25879
R44: 2Ω; R_0603; Overload Voltage (Max) 75V; Tolerance ±1%; Part 0603WAF200KT5E; LCSC C22977
TP12, TP13, TP14, TP15, TP16, TP17: RH-5015; SMD_RH-5015; LCSC C5199798
U10: BQ25672RQMR; IC_BQ25672RQMR; PARTREV A

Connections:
/CHGINT: U10.21 (~INT); also elsewhere on the board
/Power/Battery/PACK+: C40.1, C42.1, R39.1, TP12.1, U10.22 (BAT), U10.23 (BAT); also elsewhere on the board
/Power/Charger/PMID: C47.1, C50.1, C53.1, C56.1, U10.29 (PMID)
/Power/Charger/REGN: C45.1, R43.2, TP15.1, U10.5 (REGN), U10.17 (ILIM_HIZ)
/Power/Charger/VIN: C51.1, C54.1, C57.1, R44.1, TP17.1, U10.2 (VBUS), U10.3 (VBUS), U10.8 (VAC2), U10.9 (VAC1)
/SCL1: U10.14 (SCL); also elsewhere on the board
/SDA1: U10.15 (SDA); also elsewhere on the board
/VSYS: C46.1, C49.1, C52.1, C55.1, TP16.1, U10.25 (SYS); also elsewhere on the board
GND: C39.2, C40.2, C41.2, C42.2, C45.2, C46.2, C47.2, C48.2, C49.2, C50.2, C51.2, C52.2, C53.2, C54.2, C55.2, C56.2, C57.2, R41.2, R42.2, U10.10 (ACDRV2), U10.11 (ACDRV1), U10.27 (GND); also elsewhere on the board
unnamed: C48.1, R44.2
unnamed: D13.2, R43.1
unnamed: R40.2, R41.1
unnamed: C39.1, R39.2, U10.18 (BATP)
unnamed: C43.1, U10.4 (BTST1)
unnamed: C44.1, U10.19 (BTST2)
unnamed: R40.1, U10.20 (PROG)
unnamed: C41.1, U10.24 (SDRV)
unnamed: D13.1, U10.1 (STAT)
unnamed: C43.2, L1.2, TP13.1, U10.28 (SW1)
unnamed: C44.2, L1.1, TP14.1, U10.26 (SW2)
unnamed: R42.1, U10.16 (TS)

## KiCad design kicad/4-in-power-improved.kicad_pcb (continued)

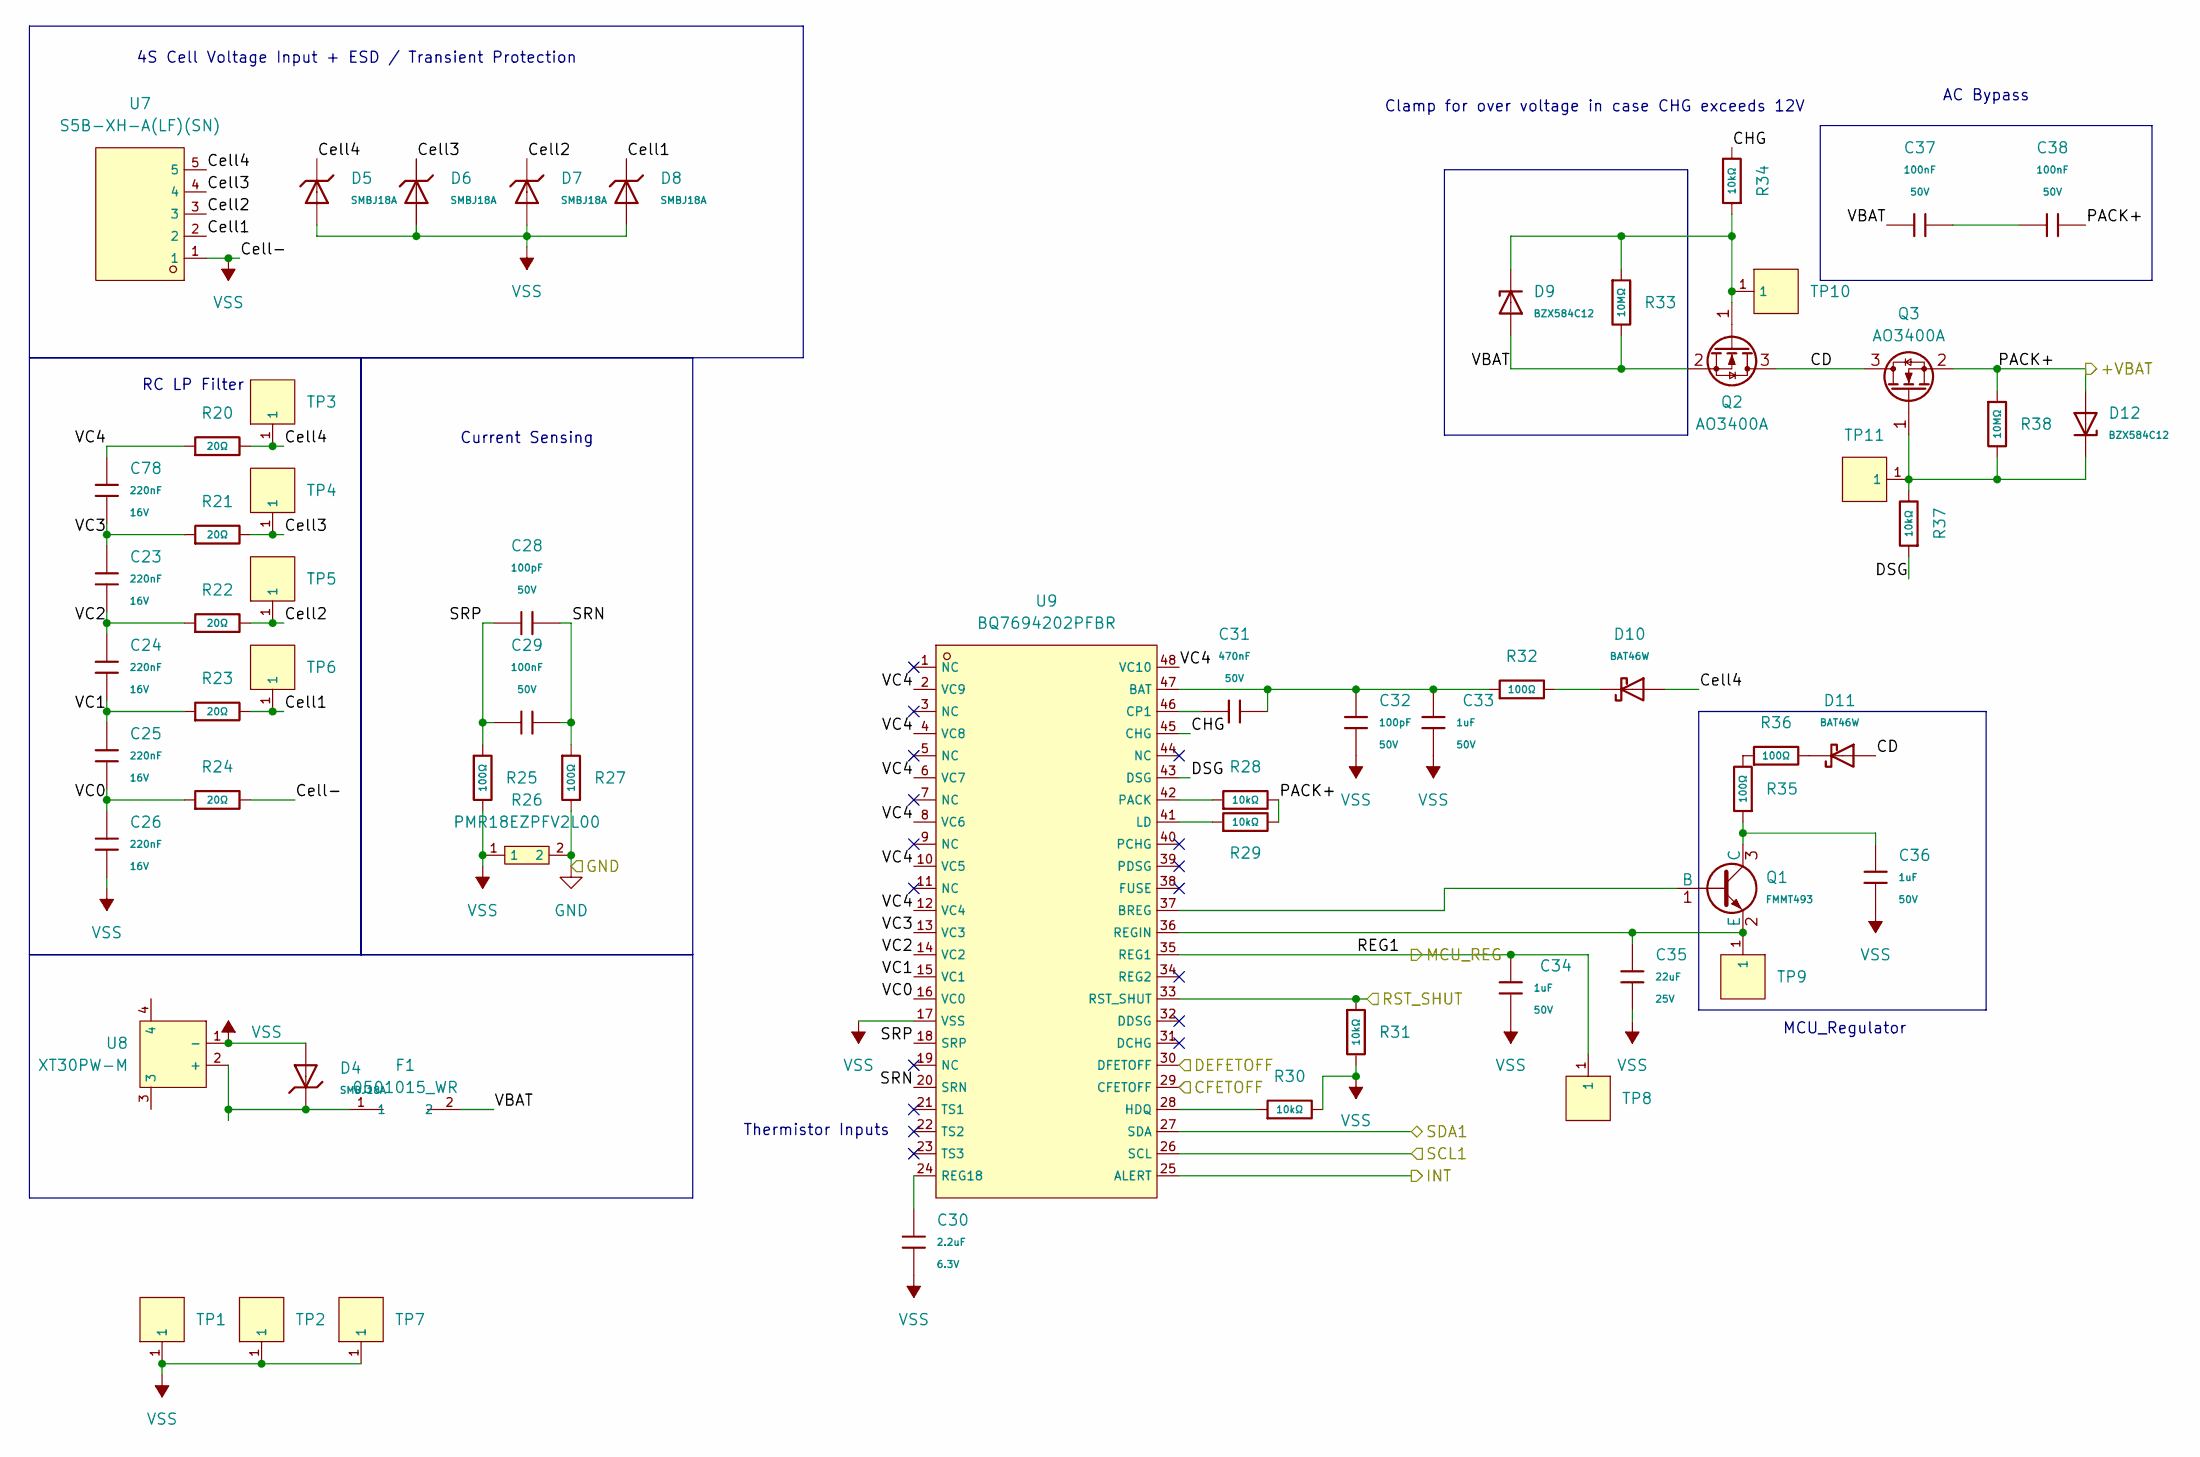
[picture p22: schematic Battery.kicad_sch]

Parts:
C23, C24, C25, C26, C78: 220nF; C_0402; Voltage Rated 16V; Tolerance ±10%; Part CL05B224KO5NNNC; LCSC C16772
C28, C32: 100pF; C_0402; Voltage Rated 50V; Tolerance ±5%; Part 0402CG101J500NT; LCSC C1546
C29, C37, C38: 100nF; C_0402; Voltage Rated 50V; Tolerance ±10%; Part CL05B104KB54PNC; LCSC C307331
C30: 2.2uF; C_0402; Voltage Rated 6.3V; Tolerance ±20%; Part CL05A225MQ5NSNC; LCSC C12530
C31: 470nF; C_0805; Voltage Rated 50V; Tolerance ±10%; Part CL21B474KBFNNNE; LCSC C13967
C33, C34, C36: 1uF; C_0603; Voltage Rated 50V; Tolerance ±10%; Part CL10A105KB8NNNC; LCSC C15849
C35: 22uF; C_0805; Voltage Rated 25V; Tolerance ±20%; Part CL21A226MAQNNNE; LCSC C45783
D4, D5, D6, D7, D8: SMBJ18A; D_SMB; Part SMBJ18A; LCSC C19077573
D9, D12: BZX584C12; D_SOD-523; Zener Voltage (Range) 11.4V~12.7V; Zener Voltage (Nom) 12V; Part BZX584C12; LCSC C22395579
D10, D11: BAT46W; D_SOD-123; Forward Voltage (Vf@If) 450mV@10mA; Reverse Voltage (Vr) 100V; Part BAT46W; LCSC C7420332
F1: 0501015_WR; F1206; LCSC C126815
Q1: FMMT493; Q_SOT-23; Part FMMT493; LCSC C28646275
Q2, Q3: AO3400A; SOT-23
R20, R21, R22, R23, R24: 20Ω; R_0603; Overload Voltage (Max) 75V; Tolerance ±1%; Part 0603WAF200JT5E; LCSC C22950
R25, R27, R32, R35, R36: 100Ω; R_0402; Overload Voltage (Max) 50V; Tolerance ±1%; Part 0402WGF1000TCE; LCSC C25076
R26: PMR18EZPFV2L00; R1206; LCSC C92124
R28, R29, R30, R31, R34, R37: 10kΩ; R_0402; Overload Voltage (Max) 50V; Tolerance ±1%; Part 0402WGF1002TCE; LCSC C25744
R33, R38: 10MΩ; R_0402; Overload Voltage (Max) 50V; Tolerance ±1%; Part 0402WGF1005TCE; LCSC C26082
TP1, TP2, TP3, TP4, TP5, TP6, TP7, TP8, TP9, TP10, TP11: RH-5015; SMD_RH-5015; LCSC C5199798
U7: S5B-XH-A(LF)(SN); CONN-TH_5P-P2.50_S5B-XH-A-LF-SN; LCSC C263757
U8: XT30PW-M; CONN-TH_XT30PW-M; LCSC C431092
U9: BQ7694202PFBR; TQFP-48_L7.0-W7.0-P0.50-LS9.0-TL; LCSC C3682863

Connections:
/BMSINT: U9.25 (ALERT); also elsewhere on the board
/KILL: U9.29 (CFETOFF); also elsewhere on the board
/MCU_REG: C34.1, TP8.1, U9.35 (REG1); also elsewhere on the board
/Power/Battery/CD: D11.2, Q2.3 (D), Q3.3 (D)
/Power/Battery/CHG: R34.2, U9.45 (CHG)
/Power/Battery/Cell1: D8.1, R23.2, TP6.1, U7.2
/Power/Battery/Cell2: D7.1, R22.2, TP5.1, U7.3
/Power/Battery/Cell3: D6.1, R21.2, TP4.1, U7.4
/Power/Battery/Cell4: D5.1, D10.2, R20.2, TP3.1, U7.5
/Power/Battery/DEFETOFF: U9.30 (DFETOFF)
/Power/Battery/DSG: R37.1, U9.43 (DSG)
/Power/Battery/PACK+: C38.2, D12.2, Q3.2 (S), R28.2, R29.2, R38.1; also elsewhere on the board
/Power/Battery/SRN: C28.2, C29.2, R27.1, U9.20 (SRN)
/Power/Battery/SRP: C28.1, C29.1, R25.1, U9.18 (SRP)
/Power/Battery/VBAT: C37.1, D9.2, F1.2, Q2.2 (S), R33.2
/Power/Battery/VC0: C25.2, C26.1, R24.1, U9.16 (VC0)
/Power/Battery/VC1: C24.2, C25.1, R23.1, U9.15 (VC1)
/Power/Battery/VC2: C23.2, C24.1, R22.1, U9.14 (VC2)
/Power/Battery/VC3: C23.1, C78.2, R21.1, U9.13 (VC3)
/Power/Battery/VC4: C78.1, R20.1, U9.2 (VC9), U9.4 (VC8), U9.6 (VC7), U9.8 (VC6), U9.10 (VC5), U9.12 (VC4), U9.48 (VC10)
/RST_SHUT: R31.1, U9.33 (RST_SHUT); also elsewhere on the board
/SCL1: U9.26 (SCL); also elsewhere on the board
/SDA1: U9.27 (SDA); also elsewhere on the board
GND: R26.2, R27.2; also elsewhere on the board
unnamed: C37.2, C38.1
unnamed: D10.1, R32.2
unnamed: D11.1, R36.2
unnamed: Q1.1 (B), U9.37 (BREG)
unnamed: C36.1, Q1.3 (C), R35.1
unnamed: C35.1, Q1.2 (E), TP9.1, U9.36 (REGIN)
unnamed: D9.1, Q2.1 (G), R33.1, R34.1, TP10.1
unnamed: D12.1, Q3.1 (G), R37.2, R38.2, TP11.1
unnamed: R35.2, R36.1
unnamed: D4.1, F1.1, U8.2 (+)
unnamed: C31.2, C32.1, C33.1, R32.1, U9.47 (BAT)
unnamed: C31.1, U9.46 (CP1)
unnamed: R30.1, U9.28 (HDQ)
unnamed: R29.1, U9.41 (LD)
unnamed: R28.1, U9.42 (PACK)
unnamed: C30.1, U9.24 (REG18)
VSS: C26.2, C30.2, C32.2, C33.2, C34.2, C35.2, C36.2, D4.2, D5.2, D6.2, D7.2, D8.2, R24.2, R25.2, R26.1, R30.2, R31.2, TP1.1, TP2.1, TP7.1, U7.1, U8.1 (-), U9.17 (VSS)

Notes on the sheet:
MCU_Regulator
Thermistor Inputs
4S Cell Voltage Input + ESD / Transient Protection
AC Bypass
Current Sensing
RC LP Filter
Clamp for over voltage in case CHG exceeds 12V

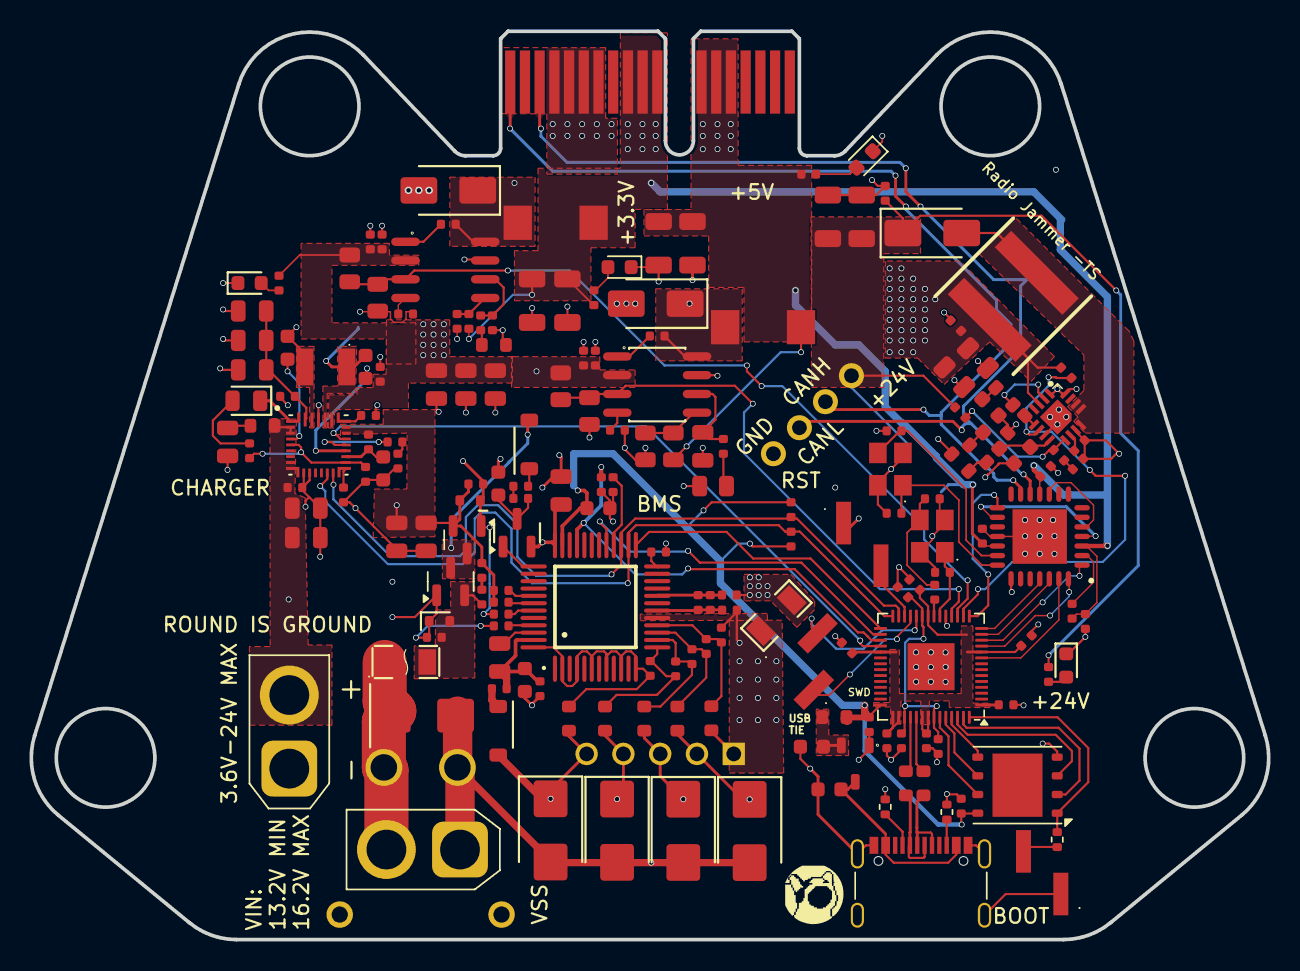
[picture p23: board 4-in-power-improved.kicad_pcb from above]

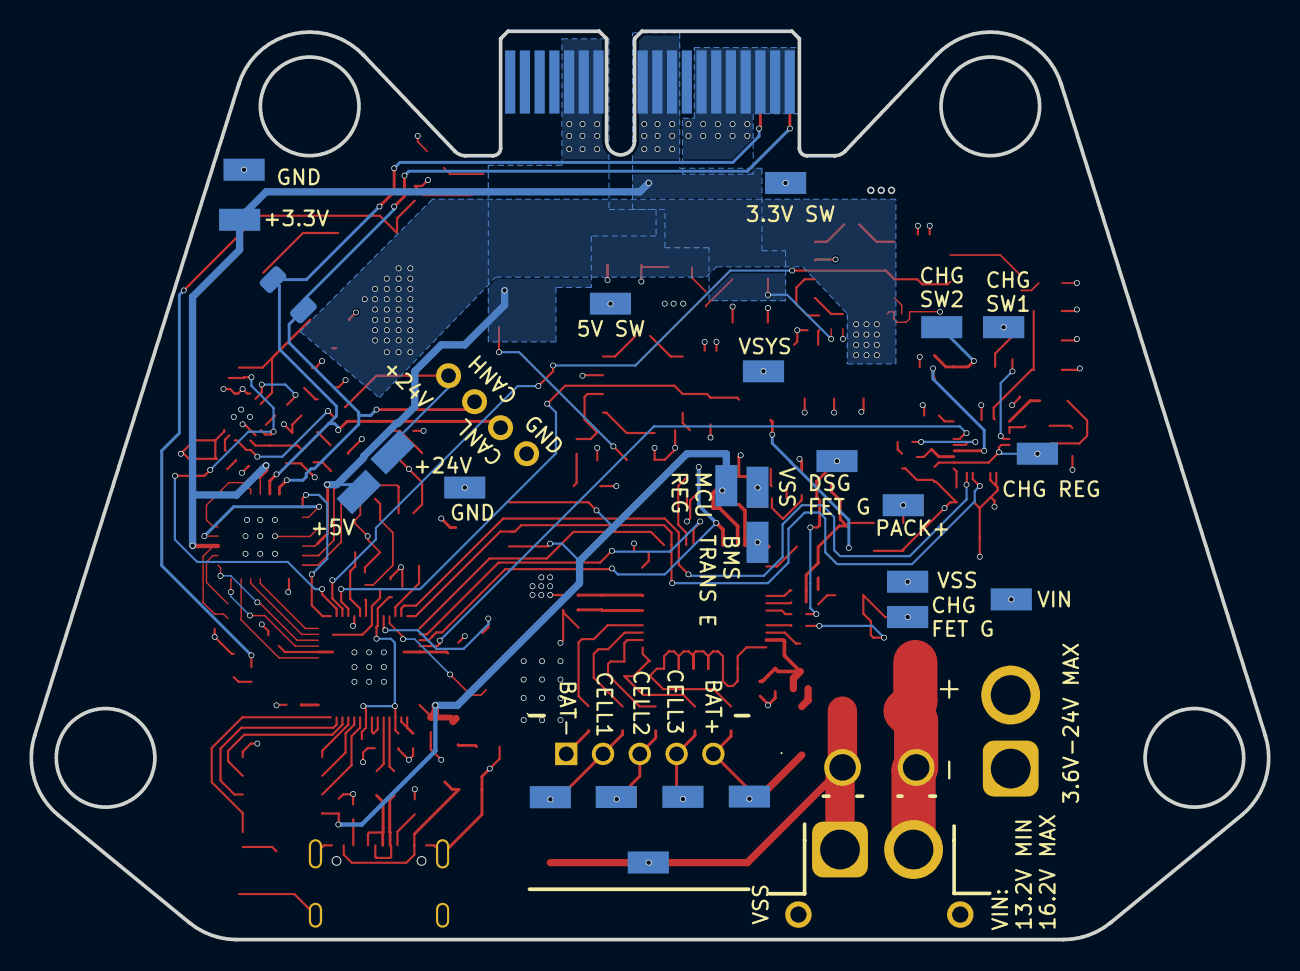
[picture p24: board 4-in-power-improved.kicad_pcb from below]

Board: 4 copper layers, 84.1 x 61.7 mm, 207 parts (28 on the bottom side), 124 nets.

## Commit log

2025-09-11 Version 1.0.0 of 4S Power Management Unit
    [4-in-power-improved.kicad_pcb, 4-in-power-improved.kicad_sch, Battery.kicad_sch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]
2025-09-11 Bucks assigned to nicholas
    [4-in-power-improved.kicad_pcb]
2025-09-12 Charger IC footprint routed RP2040 routed BMS routed xt30s and balancers router
    [4-in-power-improved.kicad_pcb, 4-in-power-improved.kicad_sch, Battery.kicad_sch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]
2025-09-13 add kicad image exporter workflow
2025-09-13 Footprint routing completed
    [4-in-power-improved.kicad_pcb, 4-in-power-improved.kicad_sch, Boost.kicad_sch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]
2025-09-13 Remapped as much of the 3d models I could
    [LED_0603_1608Metric.step, QFN-56-1EP_7x7mm_P0.4mm_EP3.2x3.2mm.step, R_0402_1005Metric.step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]
2025-09-13 Silk screen UI changes
    [4-in-power-improved.kicad_pcb, 4-in-power-improved.kicad_sch]
2025-09-13 Update README with project details and functionality
    Expanded the README to include a project overview, functionality description, and TODOs for the 4 Inch Power Management Subsystem. Moved the workflow badge to the end and added context about the desi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
2025-09-15 Replace R26 with R1206 footprint and update PCB
    Replaced the R26 resistor from an R0805 to an R1206 footprint in the PCB layout and netlist, updated associated tracks and vias, and added the new R1206 footprint file. Updated schematic, BOM, designators, and positions to reflect this change. Cleaned up related net connections and removed the old R0805 instance.
    [4-in-power-improved.kicad_pcb, Battery.kicad_sch, bom.csv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]
2025-09-15 Fixed all silk screen solder mask issues, switched 24V Xt30 connector to JST 4P with CAN lines. Board is production ready
    [4-in-power-improved.kicad_pcb, 4-in-power-improved.kicad_sch]

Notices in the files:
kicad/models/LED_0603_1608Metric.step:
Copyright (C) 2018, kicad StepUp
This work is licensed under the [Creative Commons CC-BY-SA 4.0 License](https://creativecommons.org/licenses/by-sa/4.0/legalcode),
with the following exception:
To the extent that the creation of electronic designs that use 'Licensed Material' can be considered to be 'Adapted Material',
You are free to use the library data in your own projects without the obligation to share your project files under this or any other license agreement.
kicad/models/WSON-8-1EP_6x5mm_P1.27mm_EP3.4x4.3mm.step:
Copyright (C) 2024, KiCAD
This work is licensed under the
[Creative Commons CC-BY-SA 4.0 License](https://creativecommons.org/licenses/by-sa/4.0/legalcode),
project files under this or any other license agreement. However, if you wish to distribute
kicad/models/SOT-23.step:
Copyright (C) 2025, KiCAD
